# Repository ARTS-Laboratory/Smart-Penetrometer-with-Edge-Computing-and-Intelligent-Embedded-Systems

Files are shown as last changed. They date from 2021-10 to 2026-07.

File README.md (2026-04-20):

# Smart Penetrometer with Edge Computing and Intelligent Embedded Systems (SPECIES) 
### Design and develop UAV-deployable smart sensor nodes in a network with edge computing and solar-charging capabilities for soil classification and fault detection.

<p align="center">
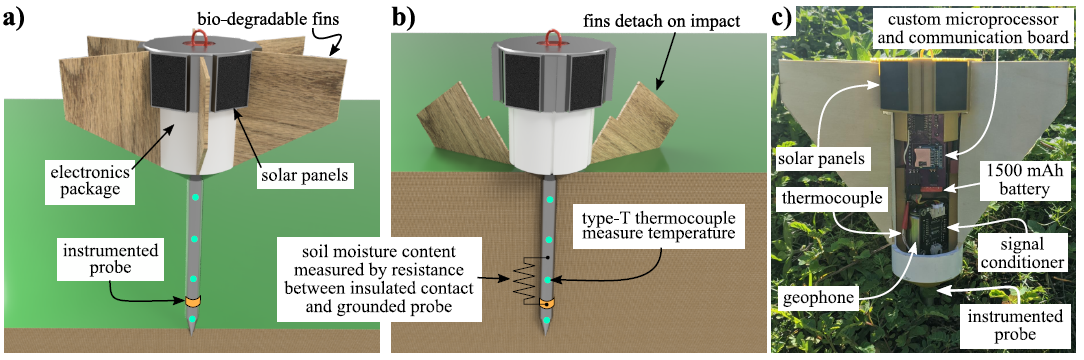
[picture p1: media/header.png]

</p>

## Licensing and Citation

[][cc-by-sa]

This work is licensed under a
[Creative Commons Attribution-ShareAlike 4.0 International License][cc-by-sa].

[cc-by-sa]: http://creativecommons.org/licenses/by-sa/4.0/
[cc-by-sa-image]: https://licensebuttons.net/l/by-sa/4.0/88x31.png
[cc-by-sa-shield]: https://img.shields.io/badge/License-CC%20BY--SA%204.0-lightgrey.svg

Cite as:

@Misc{ARTSLabSmartPenetrometerEdge,  
  author       = {ARTS-Lab},  
  howpublished = {GitHub},  
  title        = {Smart Penetrometer with Edge Computing and Intelligent Embedded Systems},  
  groups       = {ARTS-Lab},  
  url          = {https://github.com/ARTS-Laboratory/Smart-Penetrometers-with-Edge-Computing-and-Intelligent-Embedded-Systems},  
  note = {Accessed: Month dd, yyyy},   
}

<p align="center">
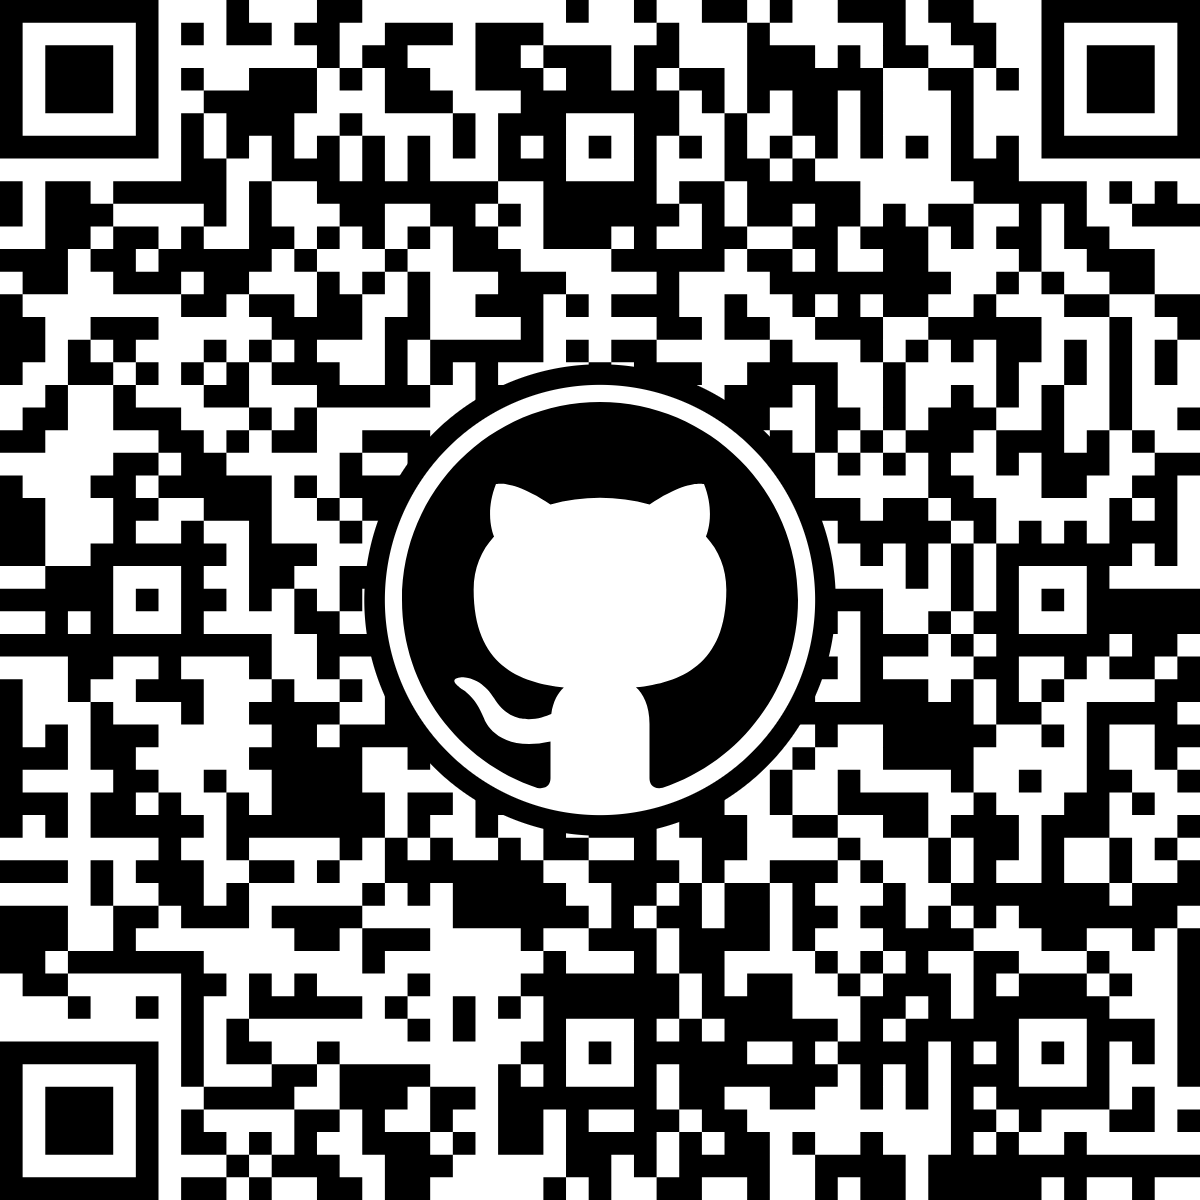
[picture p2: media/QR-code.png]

</p>
<p align="center">
QR code for repo.

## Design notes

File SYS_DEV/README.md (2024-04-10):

# Smart Penetrometer with Edge Computing and Intelligent Embedded Systems (SPECIES) - Systems Development
The SPECIES sensor package can be constructed in several versions, each named after a river with significant levee systems.

## Columbia
* The fully featured smart penetrometer with soil conductivity and temperature sensing in an intergraded spike, geophones for sensing ground movement, and  environmental condition monitoring. 

<p align="center">
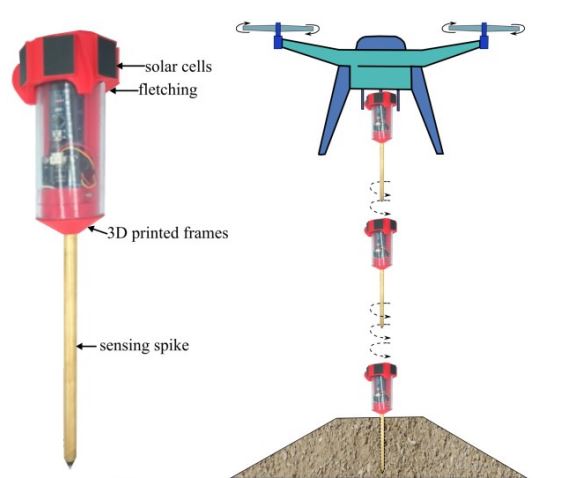
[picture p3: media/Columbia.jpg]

</p>

## Mississippi
* A wireless version of the Columbia system with only the soil moisture sensing spike.

<p align="center">
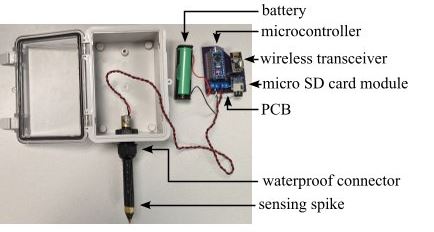
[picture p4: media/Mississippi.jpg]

</p>

## Missouri
* A geophone sensor with GPS that saves data directly to an SD card. 

<p align="center">
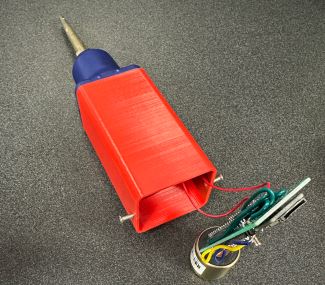
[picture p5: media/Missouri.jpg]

</p>

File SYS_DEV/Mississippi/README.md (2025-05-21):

# Mississippi

## v0.1
Files related to "spike-only" sensor package version.

### Arduino
`/Arduino/rf24_network.ino` is the code for a sensor spike node. The node's address is declared, data is collected and transmitted to the base station.

A unique address must be assigned to each node in the `this_node` variable in file `Arduino/rf24_network.ino`

`0o00` will be the address of the base station. Each node can be labeled `0o01, 0o02, etc...`

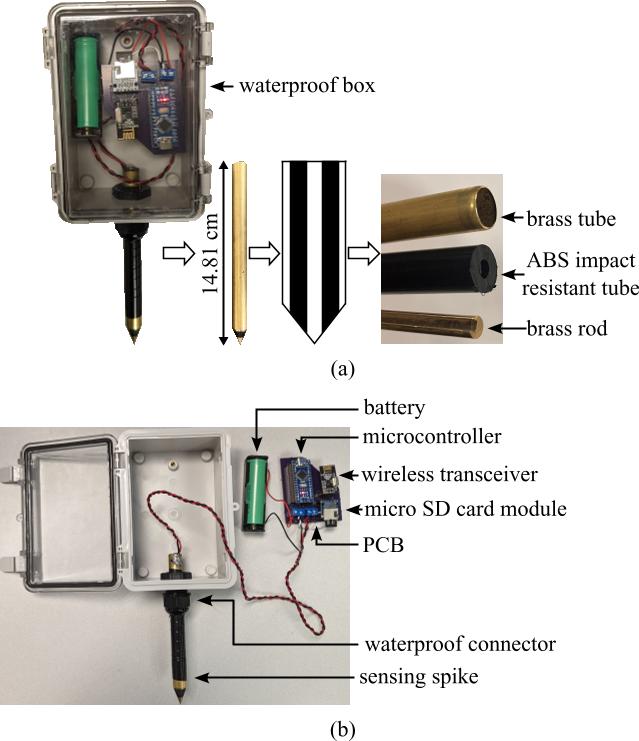
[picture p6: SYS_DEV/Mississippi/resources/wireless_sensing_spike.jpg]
Arduino Sensor Spike diagram


### RaspberryPi
`/RaspberryPi/rf24_network.py` is the code for the base station. The base station's address is established and data is recieved from the children nodes. 

All known nodes must be declared in the `OTHER_NODES` list.
Ex: for 5 nodes connected to base station `OTHER_NODES = [0o1, 0o2, 0o3, 0o4, 0o5]`

*Max of 5 nodes able to connect to nRF24L01+ chip at once.

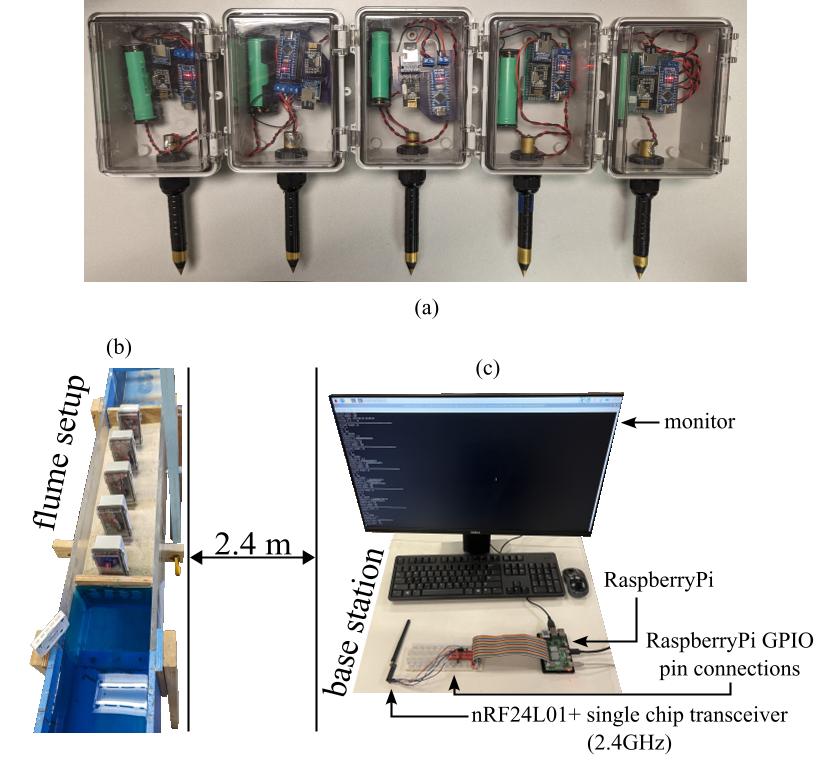
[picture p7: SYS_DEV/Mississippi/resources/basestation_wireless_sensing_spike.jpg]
Base Station diagram


### Spike PCB
PCB for a sensor spike node.

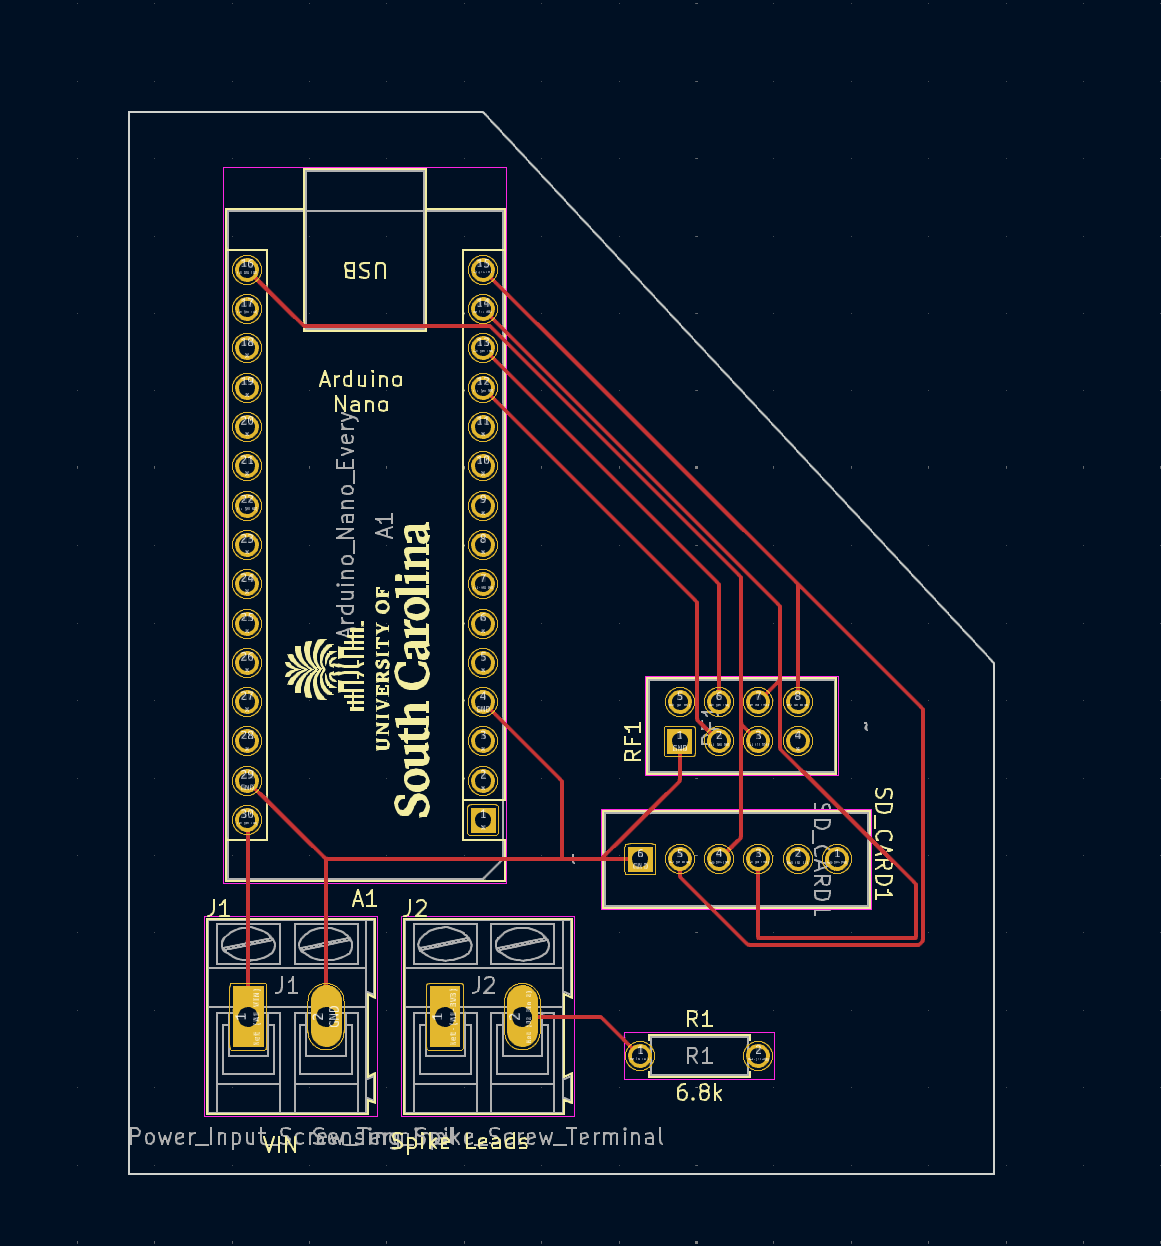
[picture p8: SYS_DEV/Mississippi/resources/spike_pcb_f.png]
Spike PCB Front
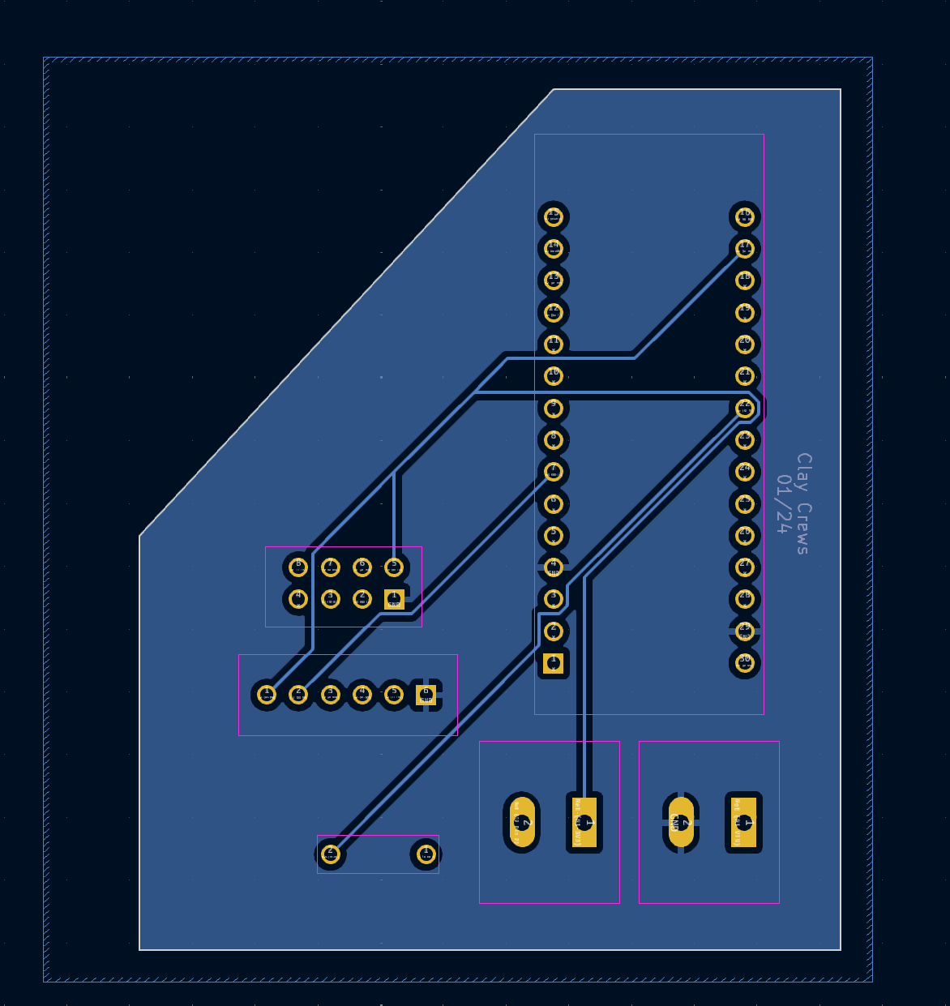
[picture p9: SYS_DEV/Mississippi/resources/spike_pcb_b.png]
Spike PCB Back


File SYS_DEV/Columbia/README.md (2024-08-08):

# Columbia 

<!-- This is a single-line comment and won't appear in the rendered README 
```angular2html      
📄 README.md
📄 image.PNG
```-->

<p align="center">
<img src="https://user-images.githubusercontent.com/87868879/166610946-1d7f9edc-2c42-431b-8995-1c52ac2c5b0f.png" alt="image" width="500"/>
</p>
<p align="center">
<img src="https://github.com/ARTS-Laboratory/Smart-Penetrometer-with-Edge-Computing-and-Intelligent-Embedded-Systems/assets/87868879/c0358ba6-607f-4f89-94c0-40613c4a618a" alt="image" width="500"/>
</p>

## [V0](V0)
### Sensor node beta version 
1. Development of sensor node prototype.
1. A sensor node that collects data and saves it to local memory.

## [V1](V1)
### Sensor node official verison (future goal)
1. Can communicate with a base station
2. Lasts for over a week.

## [V2](V2)
### Sensor node in a network (future goal)
1. Can communicate and pass data between nodes.
2. Communication protocol for passing information developed.
3. Build a way-station to collect data from a network of sensors and communicate to the cloud.

## [V3](V3)
### Autnonomous sensor node in network with edge computing (future goal)
1. Has edge-computing capabilities.
2. Can do Soil classification, fault detection, etc.

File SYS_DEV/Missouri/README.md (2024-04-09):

# Mississippi

An Open Source wireless geophone design built in parallel with SPECIES

<p align="center">

</p>
<p align="center">
The wireless geophone system being developed.
</p>

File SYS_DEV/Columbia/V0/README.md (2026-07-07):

# V0
## [V0.1](V0.1)
1. Arduino Nano for microcontroller.
2. Real-time clock and SD card module for data logging.
3. Environmental sensor, slide switch, and battery input.
4. 2-pin and 3-pin connectors for geophone and TDS sensors, respectively.
5. Op-amp and ADC for geophone signal processing.
## [V0.2](V0.2)
1. Added 4-pin connector for accelerometer.
2. Removed op-amp.
## [V0.3](V0.3)
1. Added solar power input.
2. Added 3v3 voltage regulator, Zener diode, and 2 Schottsky diodes for power management.
## [V0.4](V0.4)
1. A working version with geophone and conductivity probe.
2. Saves data to SD card.
3. No solar.
4. All needed design files in this folder.
## [V0.5](V0.5)
1. Adds wireless communication.
2. Adds solar charger.
3. Adds RTD sensor.
## [V0.6](V0.6)
1. Corrected 3V3 voltage regulator.
2. Added Op-Amp and clipper circuit for geophone.
3. Added jumpers for switching between USB and battery power.
4. Doubled amount of solar cells to six.
5. Updated housing to include geophone and and ease wiring and assembly process.
## [V0.7](V0.7)
1. More robust spike head
2. Upgrade considerations for assembly
## [Return to Main ReadMe](https://github.com/ARTS-Laboratory/Smart-Penetrometers-with-Edge-Computing-and-Intelligent-Embedded-Systems/blob/main/README.md)

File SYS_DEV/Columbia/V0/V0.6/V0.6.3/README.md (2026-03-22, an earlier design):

# V 0.6.3
## Sensor node
1. Extended battery life through hardware and software changes.
2. Removed solar charging.
3. Removed jumpers.
4. Added SN74LVC8T245DGVR logic leveler.
5. Added powerdown logic to code when idle.
6. Reduced data transimssions to once an hour.
7. Replaced solar cap with minimal cap design.

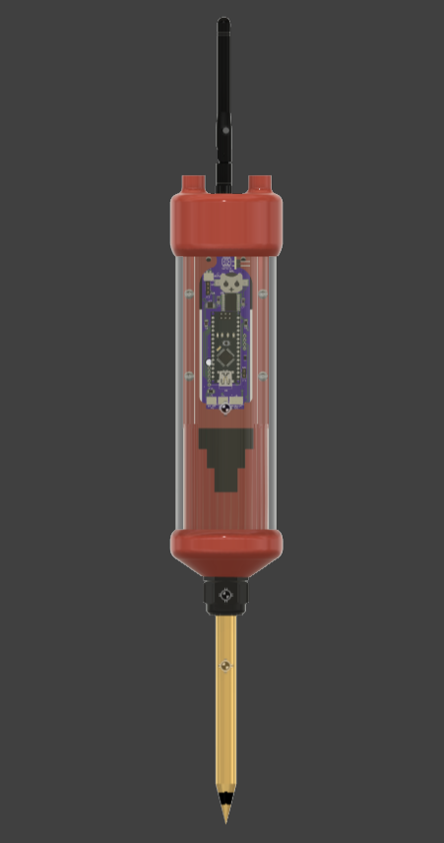
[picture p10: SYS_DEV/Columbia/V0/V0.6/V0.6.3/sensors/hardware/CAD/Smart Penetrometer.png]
Sensor


## [Return to V0.6](https://github.com/ARTS-Laboratory/Smart-Penetrometer-with-Edge-Computing-and-Intelligent-Embedded-Systems/blob/main/V0/V0.6)

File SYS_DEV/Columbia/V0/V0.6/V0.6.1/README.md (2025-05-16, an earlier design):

# V 0.6.1
Sensor node
1. A sensor node that collects data, saves it to local memory, and sends it wirelessly to gateway station.
1. Utilizes solar recharging.
1. 4-layer PCB
2. Incorporates geophone
3. Six solar cells
4. Improve waterproof seals
5. Replaced ADS1118 with ADS1115 due to spi mode incompatibility.
6. RTD, EC, and Geophone sensors all read through ADS1118.
7. Collected data stored on raspberry pi and in a dropbox client.
8. Service script initiates data collection on boot.
9. A new folder is generated each day, and each node's data is stored in a seperate file.

<p align="center">

</p>

## [Return to V0.6](https://github.com/ARTS-Laboratory/Smart-Penetrometer-with-Edge-Computing-and-Intelligent-Embedded-Systems/blob/main/V0/V0.6)

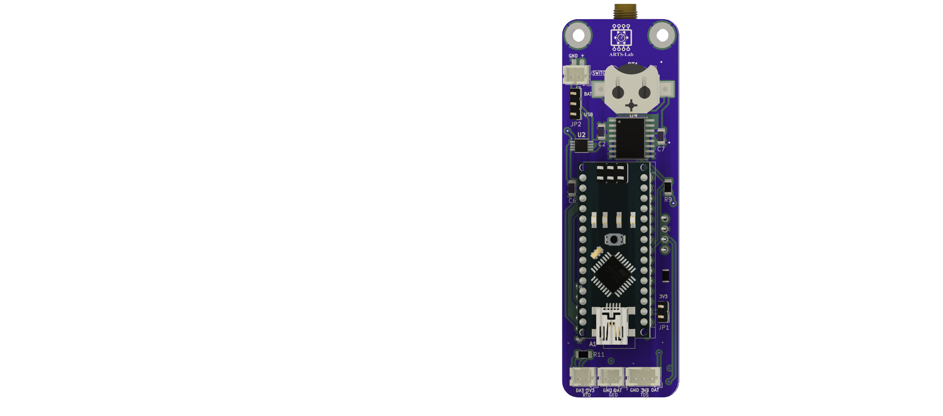
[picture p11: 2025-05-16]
SYS_DEV/Columbia/V0/V0.7/v0.7.0/sensors/hardware/PCB/smart penetrometer/smart penetrometer.kicad_pro/PCB_Front.png

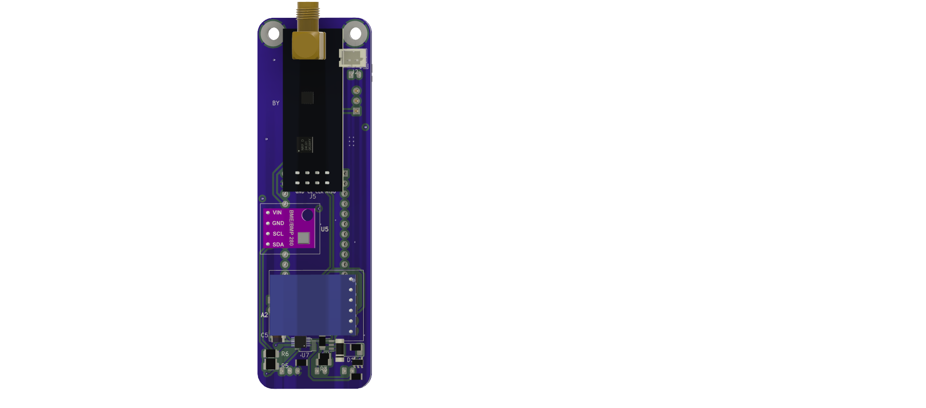
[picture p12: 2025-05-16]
SYS_DEV/Columbia/V0/V0.7/v0.7.0/sensors/hardware/PCB/smart penetrometer/smart penetrometer.kicad_pro/PCB_Back.png

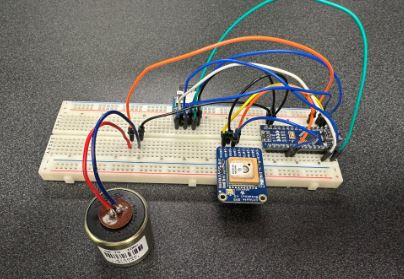
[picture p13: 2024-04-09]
SYS_DEV/Missouri/media/system.JPG

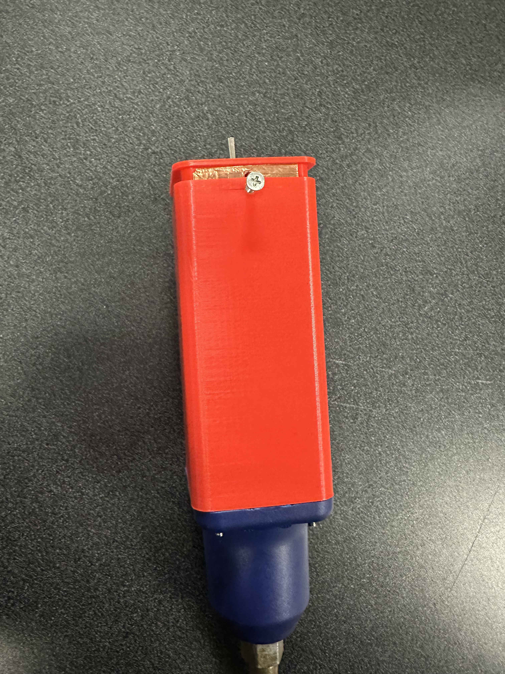
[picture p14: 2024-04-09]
SYS_DEV/Missouri/V0.2/V0.2 Housing.jpg

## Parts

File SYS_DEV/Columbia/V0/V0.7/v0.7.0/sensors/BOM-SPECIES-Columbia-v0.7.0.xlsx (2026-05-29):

Designator | Component | Amount in Inventory | Amount per Package | Individual Cost | Total Cost | Notes | Vendor 1 | Vendor 2 | Vendor 3 | Vendor 4 | Vendor 5 | Vendor 6
outer brass tube - spike probe | 260 Brass Round Tube: 17/32 in Outside Dia, 0.503 in Inside Dia, 0.014 in Wall Thick, 260, Mill |  | 1 | $6.57 | $6.57 | Slides onto the plastic tube easily. | https://www.grainger.com/product/260-Brass-Round-Tube-17-32-48KU83?opr=ODOH&analytics=FM:Order%20History
inner brass rod - spike probe | 360 Brass Rod: 1/4 in Outside Dia, 36 in Overall Lg, H02, Mill, 45,000 psi Yield Strength, Inch |  | 0.125 | $16.45 | $2.06 | longest piece with free shipping on USC contract | https://www.grainger.com/product/360-Brass-Rod-1-4-in-Outside-803H35?opr=ILOF
abs tube - spike probe | ABS Tube Stock: 3 ft Lg, 1/4 in Inside Dia, 1/2 in Outside Dia, 0.13 in Wall Thick, Opaque, Black |  | 0.167 | $13.59 | $2.27 | longest piece with free shipping on USC contract | https://www.grainger.com/product/ABS-Tube-Stock-3-ft-Lg-60CY12?opr=ODOH&analytics=FM:Order%20History
heat shrink - spike probe | SHRINK-KON Heat Shrink Tubing: 0.75 in I.D. Before Shrinking, 0.38 in I.D. After Shrinking, 10 PK |  | 0.1 | $7.76 | $0.78 |  | https://www.grainger.com/product/SHRINK-KON-Heat-Shrink-Tubing-0-75-in-3KH60?opr=ILOF
Double Split Shaft Locking Collar | 1/2" Bore Double Split Shaft Locking Collar Black Oxide Finish |  | 1 | $4.48 | $4.48 |  | https://www.mscdirect.com/product/details/65021594 | https://www.grainger.com/product/DAYTON-Shaft-Collar-2-Piece-1L698
Gorilla Glue | Gorilla Glue Original |  | 0.01 | $9.98 | $0.10 | Used between spike probe layers | https://www.grainger.com/product/GORILLA-Glue-Gen-Purpose-1TMA1 | Gorilla 8 oz. Original Glue 50008A - The Home Depot (https://www.homedepot.com/p/Gorilla-8-oz-Original-Glue-50008A/100204163)
 |  |  |  | Total | $16.25

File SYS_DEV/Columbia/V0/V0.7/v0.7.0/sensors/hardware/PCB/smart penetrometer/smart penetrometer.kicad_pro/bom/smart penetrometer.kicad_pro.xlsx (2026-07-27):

Item # | Reference | Qty | Manufacturer | Product # | Description / Value | Package | Footprint | Unit Price | Cost | Links
1 | A1 | 1 | Arduino | A000005 | ARDUINO NANO ATMEGA328 EVAL BRD |  |  | $24.90 | $24.90 | link
2 | A2 | 1 |  |  | SD_Card_Module |  | kitest:SD Module |  | $- | link
3 | BT1 | 1 | MPD | BK-870 | BATTERY RETAINER COIN 10MM SMD |  |  | $0.58 | $0.58 | link
4 |  | 1 | Renata Batteries | CR1025 | BATTERY LITHIUM 3V COIN 10MM |  |  | $1.40 | $1.40 | link
5 | C2,C6 | 2 | KEMET | C1206C104J5RACTU | C_1uF | 1206 (3216 Metric) |  | $0.24 | $0.48 | link
6 | C5,C7 | 2 | KEMET | C1206C104J5RACTU | C_0.1uF |  | Capacitor_SMD:C_1206_3216Metric |  | $- | link
7 | D1 | 1 |  |  | SMZ1_770mV |  | Diode_SMD:D_MELF |  | $- | link
8 | J1 | 1 |  |  | RTD |  | custom:JST_PH_B2B-PH-K_1x02_P2.00mm_Vertical |  | $- | link
9 | J2,J3 | 2 |  |  | Conn_01x02 |  | custom:JST_PH_B2B-PH-K_1x02_P2.00mm_Vertical |  | $- | link
10 | J4 | 1 |  |  | GEO |  | custom:JST_PH_B2B-PH-K_1x02_P2.00mm_Vertical |  | $- | link
11 | J5 | 1 |  |  | Conn_02x04 |  | Connector_PinSocket_2.54mm:PinSocket_2x04_P2.54mm_Vertical |  | $- | link
12 | J6 | 1 |  |  | EC |  | custom:JST_PH_B3B-PH-K_1x03_P2.00mm_Vertical |  | $- | link
13 | JP1 | 1 |  |  | Jumper_2 |  | Connector_PinHeader_2.54mm:PinHeader_1x02_P2.54mm_Vertical |  | $- | link
14 | JP2 | 1 |  |  | Jumper_3 |  | Connector_PinHeader_2.54mm:PinHeader_1x03_P2.54mm_Vertical |  | $- | link
15 | R1 | 1 |  |  | R_32K |  | Resistor_SMD:R_1206_3216Metric |  | $- | link
16 | R2 | 1 |  |  | R_7.5K |  | Resistor_SMD:R_1206_3216Metric |  | $- | link
17 | R3 | 1 |  |  | R_100 |  | Resistor_SMD:R_1206_3216Metric |  | $- | link
18 | R5,R6,R11 | 3 |  |  | R_10K |  | Resistor_SMD:R_1206_3216Metric |  | $- | link
19 | R9,R10 | 2 |  |  | R_1kOhm |  | Resistor_SMD:R_1206_3216Metric |  | $- | link
20 | U1 | 1 |  |  | LM321 |  | Package_TO_SOT_SMD:SOT-23-5 |  | $0.10 | link (https://www.digikey.com/en/products/detail/shenzhen-slkormicro-semicon-co-ltd/LM321/21852988)
21 | U2 | 1 |  |  | ADP124ARHZ-3.3-R7 |  | footprint:RH_8_1_ADI |  | $2.52 | link1 (https://www.digikey.com/en/products/detail/analog-devices-inc/ADP124ARHZ-3.3-R7/2237789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) | link2 (https://www.ebay.com/itm/365432072865?var=635230515876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)
22 | U4 | 1 |  |  | DS3231M |  | Package_SO:SOIC-16W_7.5x10.3mm_P1.27mm |  | $- | link
23 | U5 | 1 |  |  | BME260 |  | kitest:BME260 |  | $- | link
24 | U7 | 1 |  |  | ADS1115IDGS |  | Package_SO:TSSOP-10_3x3mm_P0.5mm |  | $5.28 | link1 (https://www.digikey.com/en/products/detail/texas-instruments/ADS1115IDGSR/2231567) | link2 (https://www.ebay.com/itm/293687781658?_skw=ADS1115IDGSR&itmmeta=01KYGADFZC6XKXNJYDE79P6MAW)
 |  |  |  |  |  |  |  | Total Cost | $35.26

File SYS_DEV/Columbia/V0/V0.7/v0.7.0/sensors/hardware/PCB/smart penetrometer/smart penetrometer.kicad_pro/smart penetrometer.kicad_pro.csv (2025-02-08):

Source: | C:\USC\Smart-Penetrometer-with-Edge-Computing-and-Intelligent-Embedded-Systems\System_development\Columbia\V0\V0.6\V0.6.1\sensor_node\hardware_design\PCB\smart penetrometer\smart penetrometer.kicad_sch
Date: | 2/8/2025 1:21:20 AM
Tool: | Eeschema 7.0.2
Generator: | C:\Program Files\KiCad\7.0\bin\scripting\plugins/bom_csv_grouped_by_value.py
Component Count: | 29
Collated Components:
Item | Qty | Reference(s) | Value | LibPart | Footprint | Datasheet | DNP | 1 | 2 | 3 | 4
1 | 1 | A1 | Arduino Nano | smart-penetrometer-update-rescue:Arduino_Nano_v3.x-MCU_Module-kitest-rescue-smart-penetrometer-rescue-smart-penetrometer-update-rescue | Module:Arduino_Nano | http://www.mouser.com/pdfdocs/Gravitech_Arduino_Nano3_0.pdf
2 | 1 | A2 | SD_Card_Module | smart-penetrometer-update-rescue:SD_Card_Module-Charleslabs_Parts-kitest-rescue-smart-penetrometer-rescue-smart-penetrometer-update-rescue | kitest:SD Module
3 | 1 | BT1 | Battery_Cell | Device:Battery_Cell | kitest:battery_holder_10mm | ~
4 | 2 | C2, C6 | C_1uF | Device:C_Small | Capacitor_SMD:C_1206_3216Metric | ~
5 | 2 | C5, C7 | C_0.1uF | Device:C_Small | Capacitor_SMD:C_1206_3216Metric | ~
6 | 1 | D1 | SMZ1_770mV | Diode:SMZxxx | Diode_SMD:D_MELF | https://diotec.com/tl_files/diotec/files/pdf/datasheets/smz1.pdf
7 | 2 | H1, H2 | MountingHole_Pad | Mechanical:MountingHole_Pad | MountingHole:MountingHole_3.2mm_M3_Pad | ~
8 | 2 | J2, J3 | Conn_01x02 | Connector:Conn_01x02_Female | Connector_PinSocket_2.54mm:PinSocket_1x02_P2.54mm_Horizontal | ~
9 | 1 | J4 | Conn_01x07_Female | Connector:Conn_01x07_Female | Connector_PinSocket_2.54mm:PinSocket_1x07_P2.54mm_Horizontal | ~
10 | 1 | J5 | Conn_02x04 | Connector_Generic_MountingPin:Conn_02x04_Odd_Even_MountingPin | Connector_PinSocket_2.54mm:PinSocket_2x04_P2.54mm_Vertical | ~
11 | 1 | JP1 | Jumper_2 | Jumper:Jumper_2_Open | Connector_PinHeader_2.54mm:PinHeader_1x02_P2.54mm_Vertical | ~
12 | 1 | JP2 | Jumper_3 | Jumper:Jumper_3_Open | Connector_PinHeader_2.54mm:PinHeader_1x03_P2.54mm_Vertical | ~
13 | 1 | R1 | R_32K | Device:R_Small_US | Resistor_SMD:R_1206_3216Metric | ~
14 | 1 | R2 | R_7.5K | Device:R_Small_US | Resistor_SMD:R_1206_3216Metric | ~
15 | 1 | R3 | R_100 | Device:R_Small_US | Resistor_SMD:R_1206_3216Metric | ~
16 | 3 | R5, R6, R11 | R_10K | Device:R_Small_US | Resistor_SMD:R_1206_3216Metric | ~
17 | 2 | R9, R10 | R_1kOhm | Device:R_Small_US | Resistor_SMD:R_1206_3216Metric | ~
18 | 1 | U1 | LM321 | Amplifier_Operational:LM321 | Package_TO_SOT_SMD:SOT-23-5 | http://www.ti.com/lit/ds/symlink/lm321.pdf
19 | 1 | U2 | ADP124ARHZ-3.3-R7 | smart penetrometer update-rescue:ADP124ARHZ-3.3-R7 | footprint:RH_8_1_ADI | https://www.analog.com/media/en/technical-documentation/data-sheets/ADP124_125.pdf
20 | 1 | U4 | DS3231M | Timer_RTC:DS3231M | Package_SO:SOIC-16W_7.5x10.3mm_P1.27mm | http://datasheets.maximintegrated.com/en/ds/DS3231.pdf
21 | 1 | U5 | BME260 | 4xxx:4023 | kitest:BME260 | http://www.intersil.com/content/dam/Intersil/documents/cd40/cd4011bms-12bms-23bms.pdf |  | SDA | SCL | V | G
22 | 1 | U7 | ADS1115IDGS | Analog_ADC:ADS1115IDGS | Package_SO:TSSOP-10_3x3mm_P0.5mm | http://www.ti.com/lit/ds/symlink/ads1113.pdf

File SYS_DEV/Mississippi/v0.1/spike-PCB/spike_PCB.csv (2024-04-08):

Source: | /home/jccrews/Documents/SensorSpike/spike_PCB/spike_PCB.kicad_sch
Date: | Wed 10 Jan 2024 12:13:42 PM EST
Tool: | Eeschema 7.0.10-7.0.10~ubuntu20.04.1
Generator: | /usr/share/kicad/plugins/bom_csv_grouped_by_value_with_fp.py
Component Count: | 6
Ref | Qnty | Value | Cmp name | Footprint | Description | Vendor | DNP
A1 | 1 | Arduino_Nano_Every | Arduino_Nano_Every | Module:Arduino_Nano | Arduino Nano Every
J1 | 1 | Power_Input_Screw_Terminal | Screw_Terminal_01x02 | TerminalBlock:TerminalBlock_Altech_AK300-2_P5.00mm | Generic screw terminal, single row, 01x02, script generated (kicad-library-utils/schlib/autogen/connector/)
J2 | 1 | Sensing_Spike_Screw_Terminal | Screw_Terminal_01x02 | TerminalBlock:TerminalBlock_Altech_AK300-2_P5.00mm | Generic screw terminal, single row, 01x02, script generated (kicad-library-utils/schlib/autogen/connector/)
R1 | 1 | 6.8k | R_US | Resistor_THT:R_Axial_DIN0207_L6.3mm_D2.5mm_P7.62mm_Horizontal | Resistor, US symbol
RF1 | 1 | ~ | nRF24L01 | spike_PCB:nRF24L01
SD_CARD1 | 1 | ~ | SD_Card_Module | spike_PCB:SD_Card_Module

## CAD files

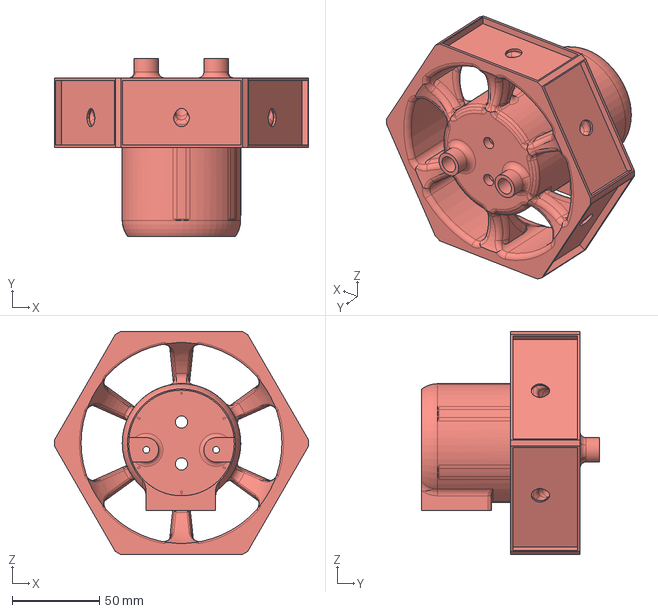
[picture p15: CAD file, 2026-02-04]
SYS_DEV/Columbia/V0/V0.7/v0.7.0/sensors/hardware/CAD/solar cap 2_.stp
145.7 x 101.8 x 128.0 mm

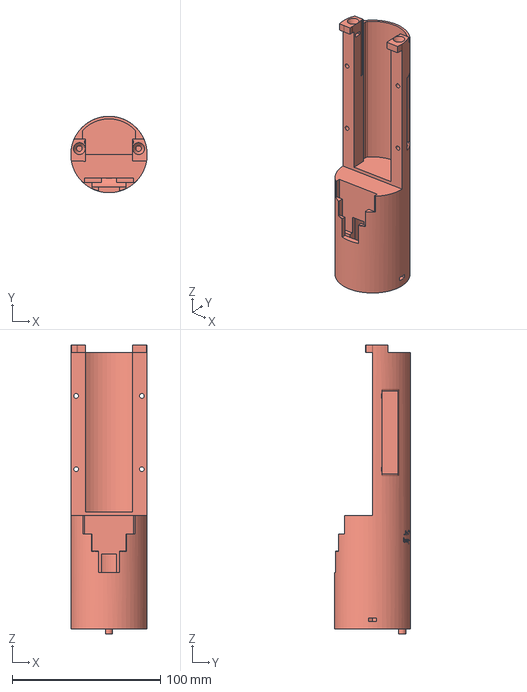
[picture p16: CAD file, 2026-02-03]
SYS_DEV/Columbia/V0/V0.7/v0.7.0/sensors/hardware/CAD/body_v0.7.0.stp
51.6 x 51.6 x 195.2 mm

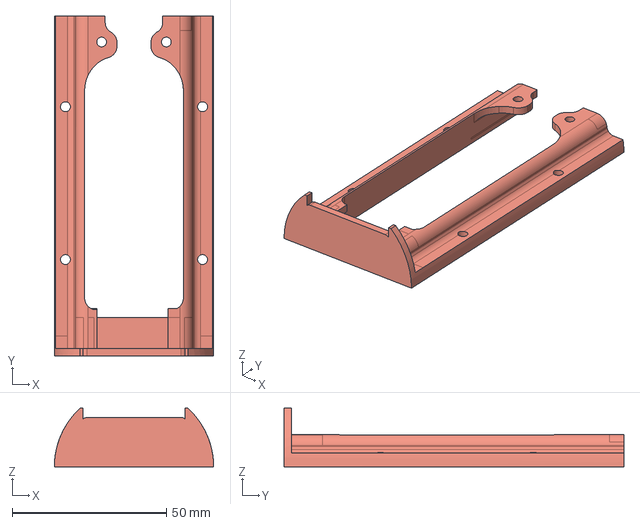
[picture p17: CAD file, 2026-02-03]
SYS_DEV/Columbia/V0/V0.7/v0.7.0/sensors/hardware/CAD/plate.stp
51.6 x 110.2 x 19.0 mm

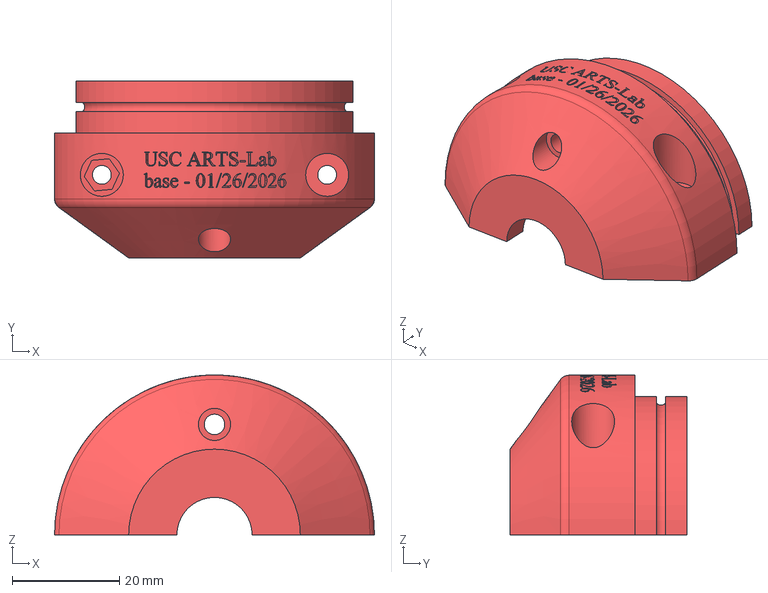
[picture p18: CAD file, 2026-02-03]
SYS_DEV/Columbia/V0/V0.7/v0.7.0/sensors/hardware/CAD/base_v0.7.0.stp
59.6 x 33.0 x 29.8 mm

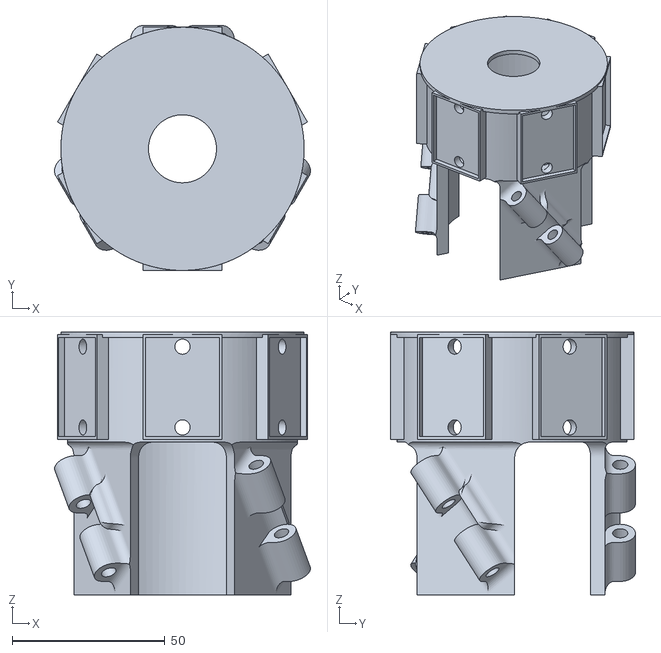
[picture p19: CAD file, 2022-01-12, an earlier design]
SYS_DEV/Columbia/V0/V0.1/V0.1.1/hardware_design/CAD/Solar panel attachment with hinge_v1.stl
83.7 x 80.1 x 86.0

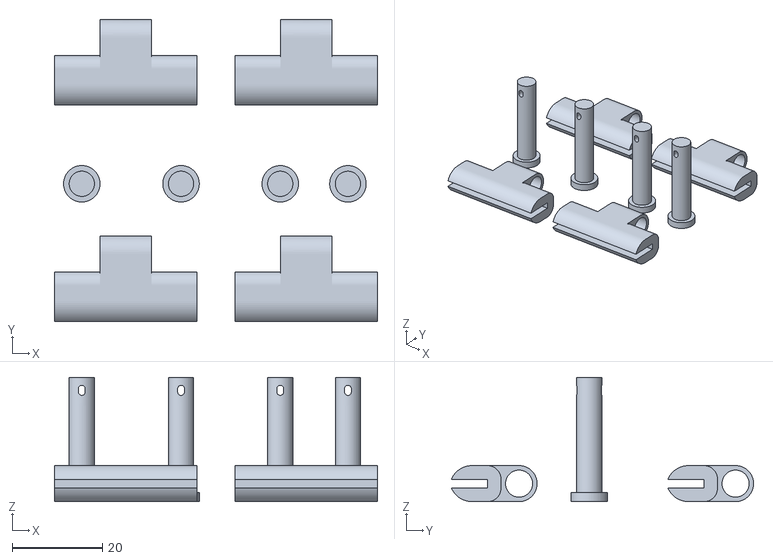
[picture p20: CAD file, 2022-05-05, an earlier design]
SYS_DEV/Columbia/V0/V0.2/V0.2.0/hardware_design/CAD/hinge and hinge pin v2.stl
71.6 x 67.0 x 27.6

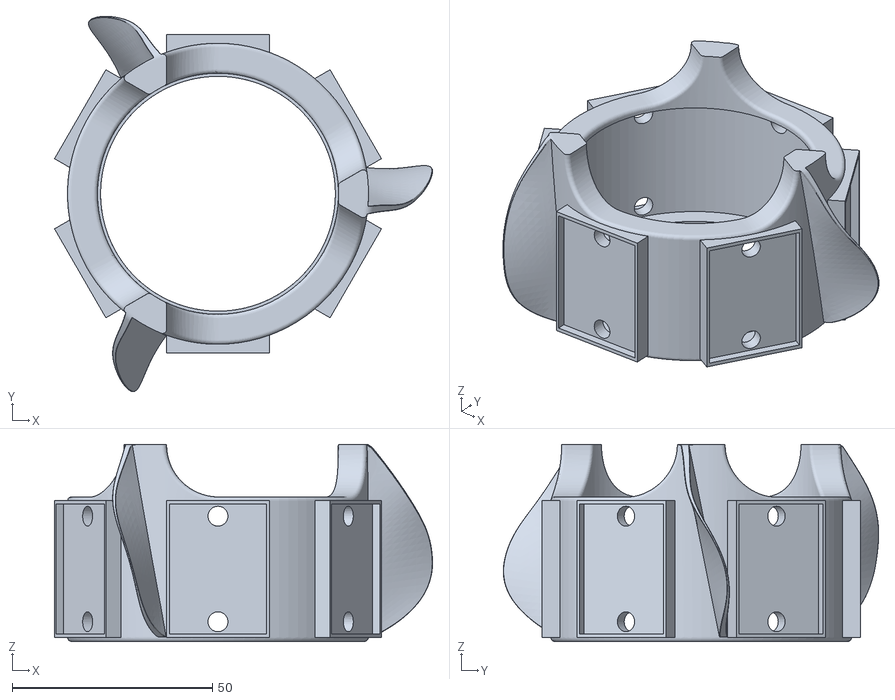
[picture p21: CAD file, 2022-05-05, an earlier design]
SYS_DEV/Columbia/V0/V0.3/V0.3.0/hardware_design/CAD/solar cells with fletching.stl
94.5 x 93.8 x 49.3

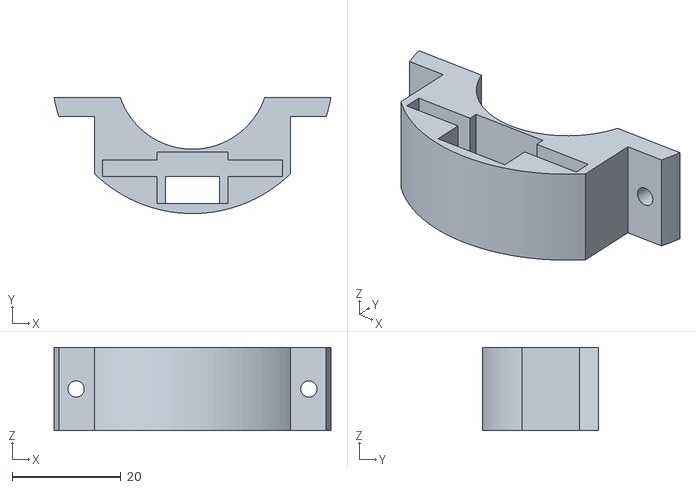
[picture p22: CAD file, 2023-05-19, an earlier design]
SYS_DEV/Columbia/V0/V0.4/V0.4.0/hardware_design/CAD/Housing v4 part 2.stl
50.9 x 21.3 x 15.2

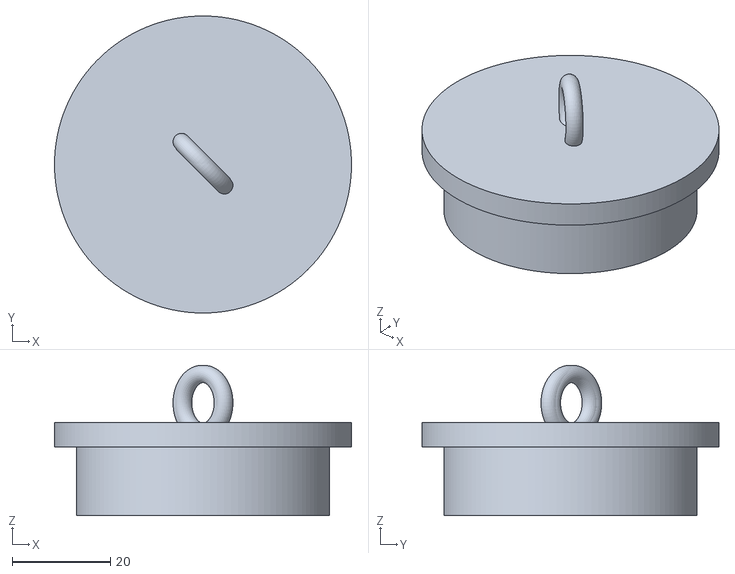
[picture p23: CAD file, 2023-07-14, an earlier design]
SYS_DEV/Columbia/V0/V0.4/V0.4.1/hardware_design/CAD/sensor_cap_v4.1.stl
60.6 x 60.6 x 30.7

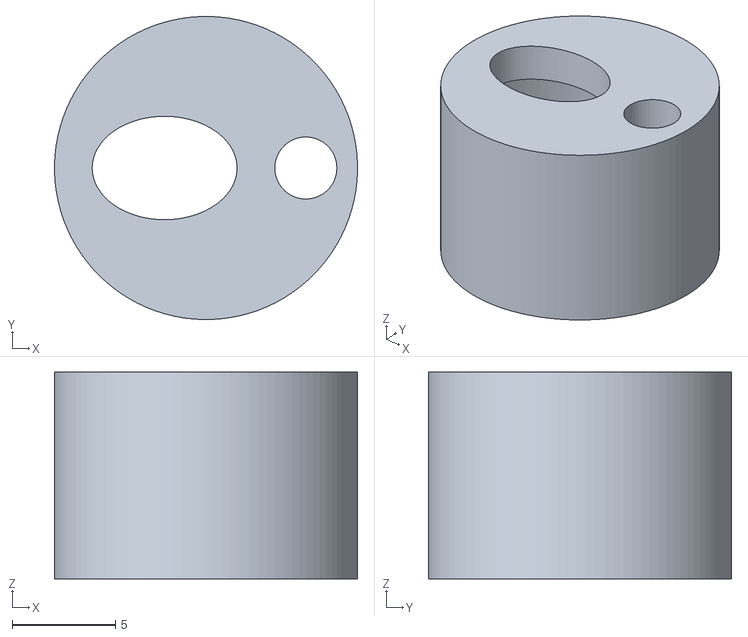
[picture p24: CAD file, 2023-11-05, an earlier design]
SYS_DEV/Columbia/V0/V0.5/V0.5.0/hardware_design/CAD/Housing3 V0.5.0b.stl
14.6 x 14.6 x 10.00

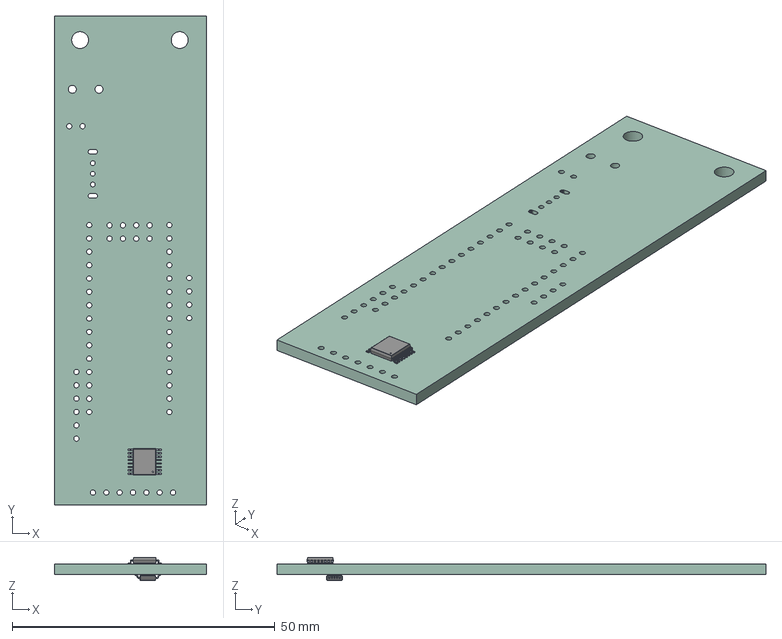
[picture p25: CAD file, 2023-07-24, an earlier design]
SYS_DEV/Columbia/V0/V0.5/V0.5.0/hardware_design/PCB/smart penetrometer/smart penetrometer.step
29.0 x 93.0 x 4.38 mm
smart penetrometer PCB

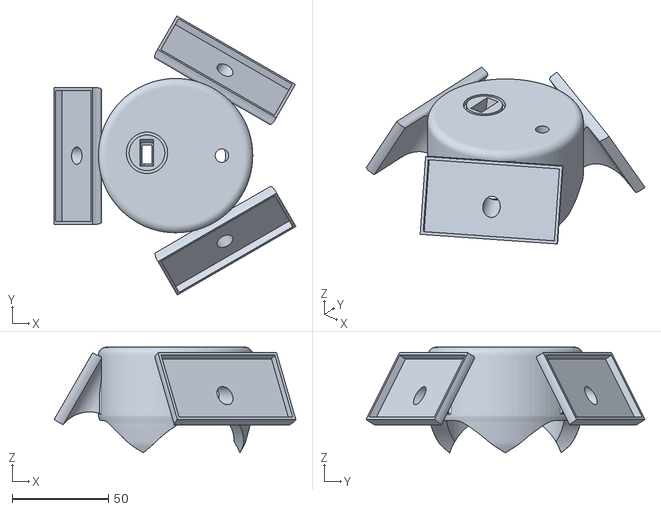
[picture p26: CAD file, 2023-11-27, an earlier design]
SYS_DEV/Columbia/V0/V0.5/V0.5.1/hardware_design/CAD/Solar Cap_.stl
125.3 x 144.6 x 54.8

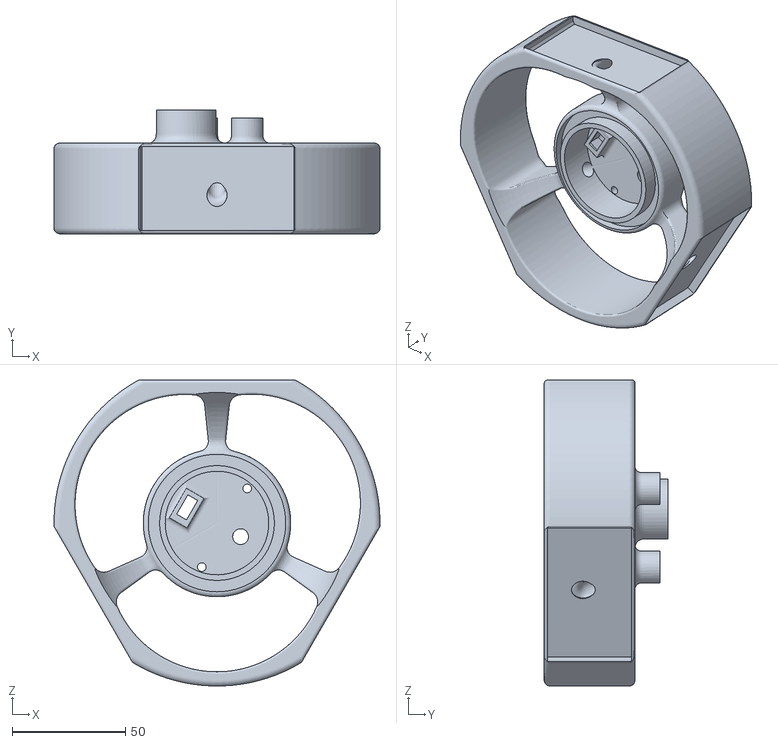
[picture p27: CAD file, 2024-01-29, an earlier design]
SYS_DEV/Columbia/V0/V0.5/V0.5.2/hardware_design/CAD/Solar Cap.stl
143.7 x 54.5 x 134.9

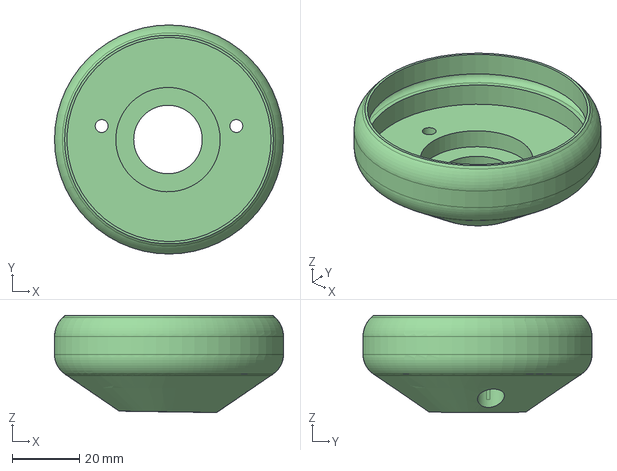
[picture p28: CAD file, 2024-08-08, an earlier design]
SYS_DEV/Columbia/V0/V0.6/V0.6.0/sensor_node/hardware_design/CAD/Housing3.step
68.0 x 68.0 x 28.8 mm

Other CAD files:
SYS_DEV/Columbia/V0/V0.6/V0.6.0/sensor_node/hardware_design/PCB/smart penetrometer/smart penetrometer.step
SYS_DEV/Columbia/V0/V0.6/V0.6.1/sensor_node/hardware_design/CAD/Housing2.step
SYS_DEV/Columbia/V0/V0.1/V0.1.0/hardware_design/CAD/housing v1.f3d
SYS_DEV/Columbia/V0/V0.1/V0.1.0/hardware_design/CAD/modified solar cell attachment v1.f3d
SYS_DEV/Columbia/V0/V0.1/V0.1.0/hardware_design/CAD/sensor_cap v1.f3z
SYS_DEV/Columbia/V0/V0.1/V0.1.1/hardware_design/CAD/Housing_v2.f3d
SYS_DEV/Columbia/V0/V0.1/V0.1.1/hardware_design/CAD/Housing_v2.stl
SYS_DEV/Columbia/V0/V0.1/V0.1.1/hardware_design/CAD/Housing_v2_part2.f3d
SYS_DEV/Columbia/V0/V0.1/V0.1.1/hardware_design/CAD/Housing_v2_part2.stl
SYS_DEV/Columbia/V0/V0.1/V0.1.1/hardware_design/CAD/Solar panel attachment with hinge_v1.f3d
SYS_DEV/Columbia/V0/V0.1/V0.1.1/hardware_design/CAD/cap_v2.f3z
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

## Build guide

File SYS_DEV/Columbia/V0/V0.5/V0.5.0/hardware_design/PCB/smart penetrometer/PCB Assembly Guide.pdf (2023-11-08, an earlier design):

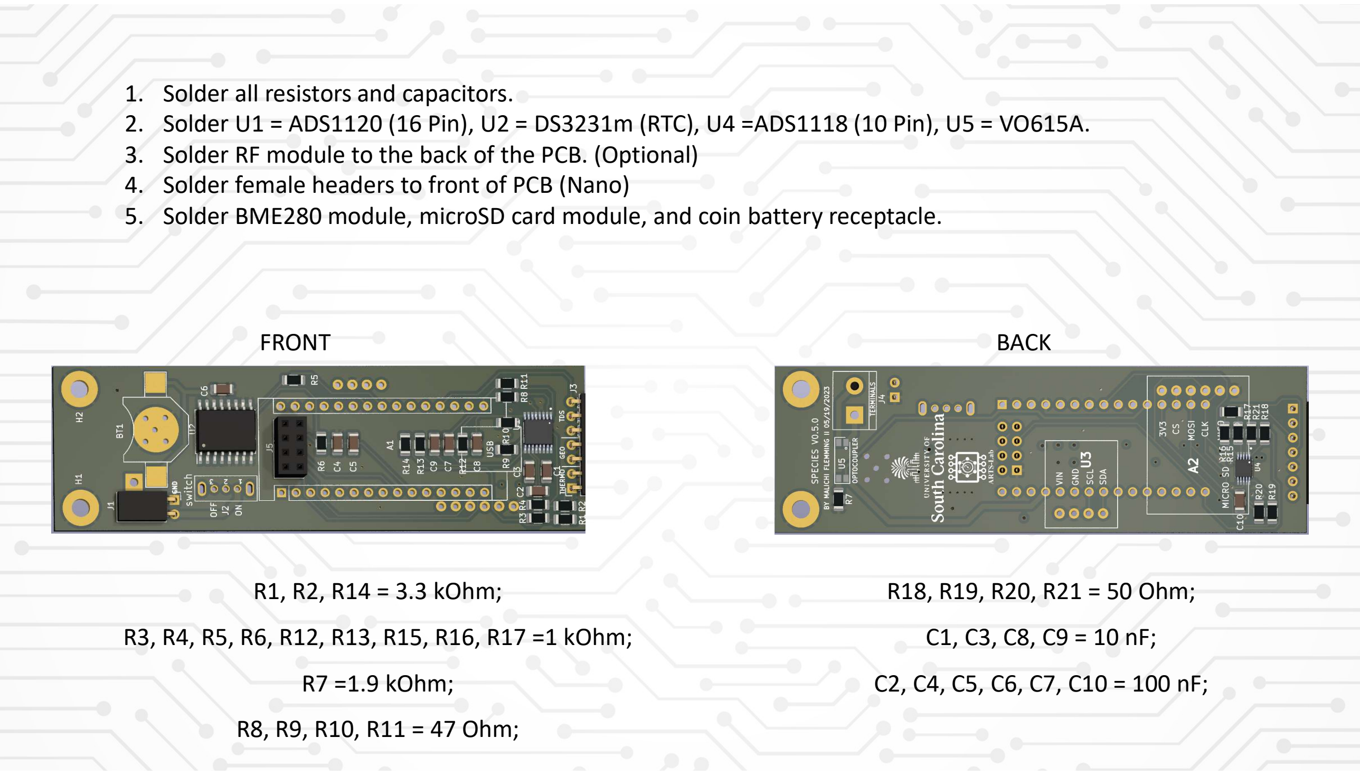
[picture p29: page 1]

R1, R2, R14 = 3.3 kOhm;
R3, R4, R5, R6, R12, R13, R15, R16, R17 =1 kOhm; R7 =1.9 kOhm;
R8, R9, R10, R11 = 47 Ohm;

R18, R19, R20, R21 = 50 Ohm; C1, C3, C8, C9 = 10 nF;
C2, C4, C5, C6, C7, C10 = 100 nF;
1. Solder all resistors and capacitors.
2. Solder U1 = ADS1120 (16 Pin), U2 = DS3231m (RTC), U4 =ADS1118 (10 Pin), U5 = VO615A.

### 3. Solder RF module to the back of the PCB. (Optional) 4. Solder female headers to front of PCB (Nano)

5. Solder BME280 module, microSD card module, and coin battery receptacle.
FRONT | BACK

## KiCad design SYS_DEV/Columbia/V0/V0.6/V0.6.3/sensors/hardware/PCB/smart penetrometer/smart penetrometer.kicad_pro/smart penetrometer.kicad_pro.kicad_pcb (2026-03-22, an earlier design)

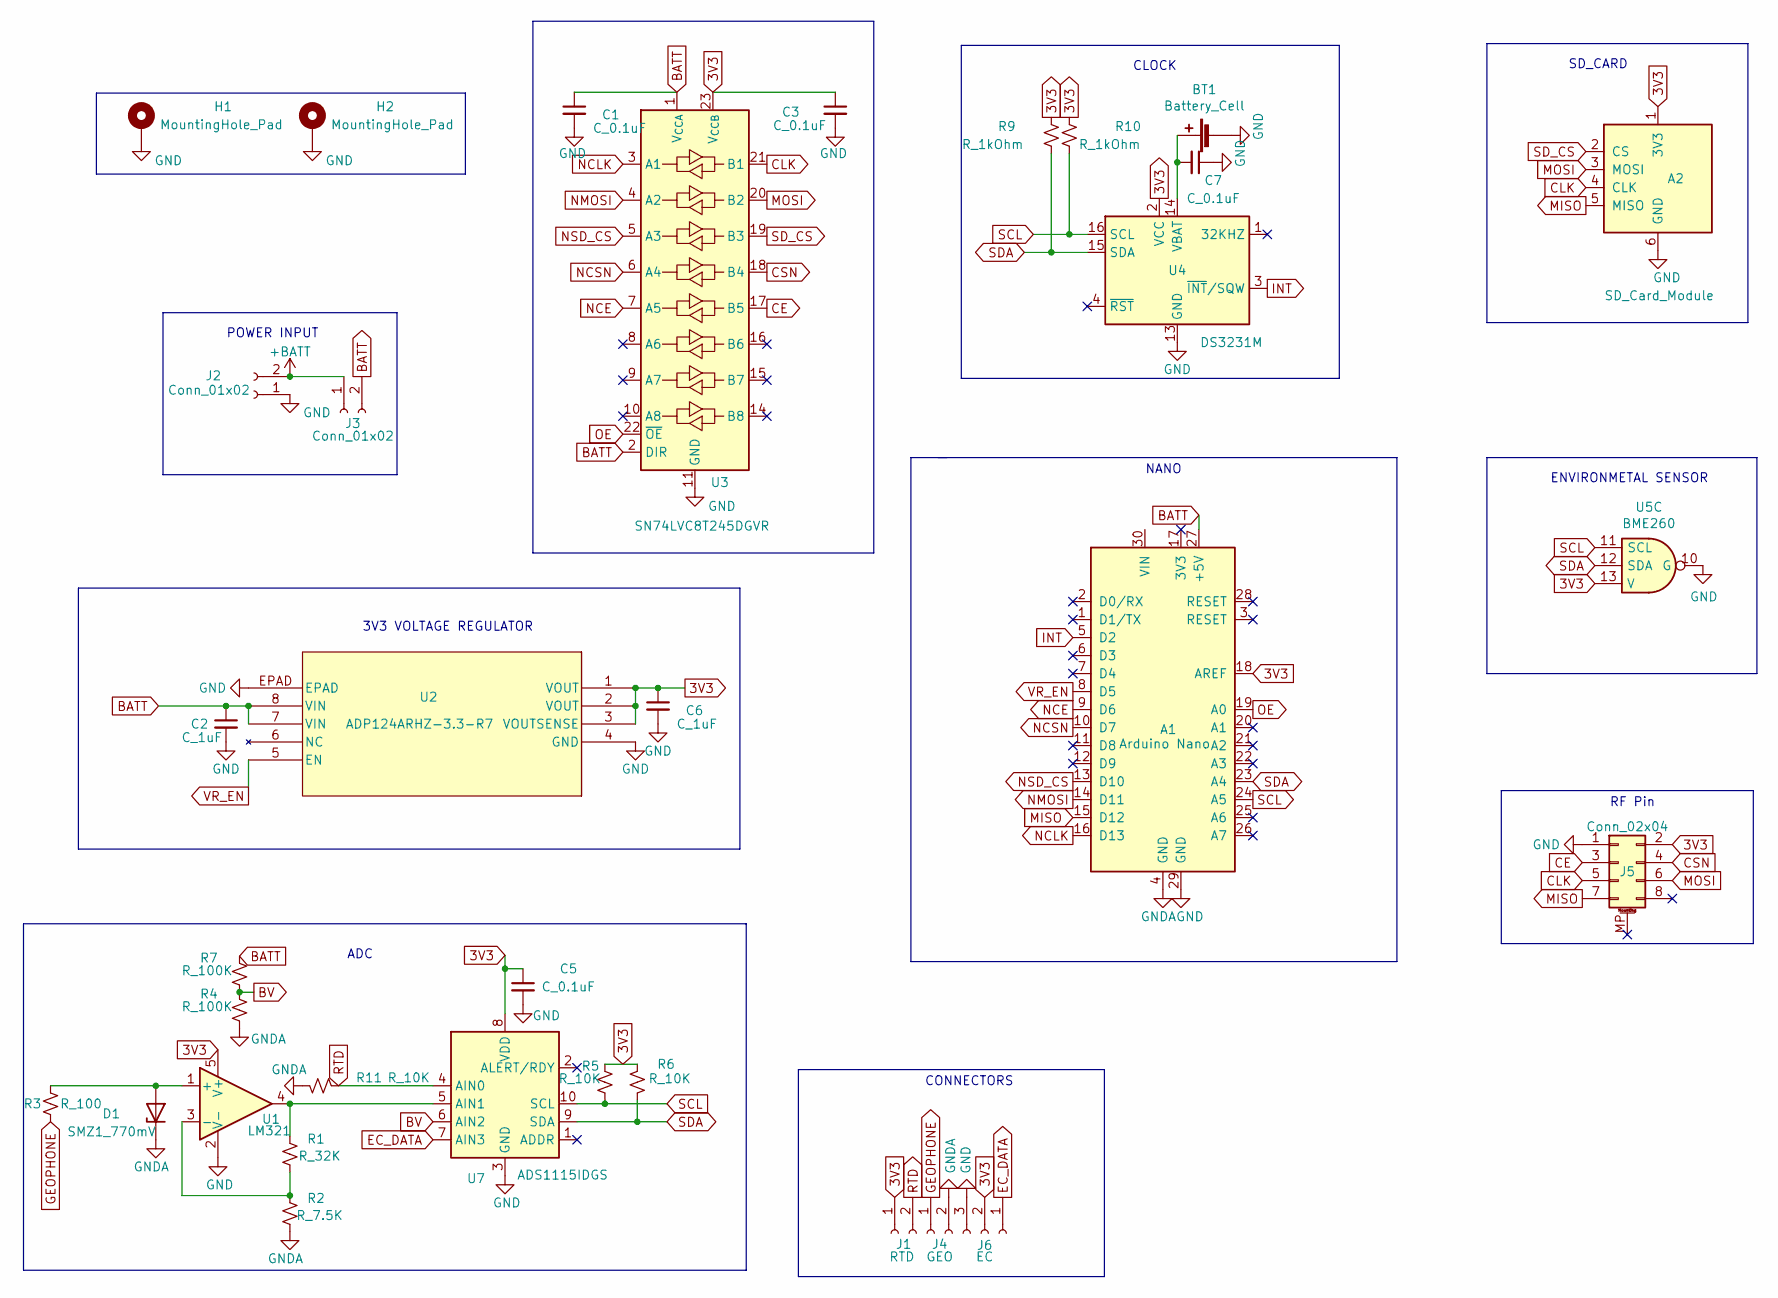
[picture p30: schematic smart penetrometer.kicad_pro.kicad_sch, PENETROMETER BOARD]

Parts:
A1: Arduino Nano; Arduino_Nano
A2: SD_Card_Module; SD Module
BT1: Battery_Cell; battery_holder_10mm
C1, C3, C5, C7: C_0.1uF; C_1206_3216Metric
C2, C6: C_1uF; C_1206_3216Metric
D1: SMZ1_770mV; D_MELF
H1, H2: MountingHole_Pad; MountingHole_3.2mm_M3_Pad
J1: RTD; JST_PH_B2B-PH-K_1x02_P2.00mm_Vertical
J2, J3: Conn_01x02; JST_PH_B2B-PH-K_1x02_P2.00mm_Vertical
J4: GEO; JST_PH_B2B-PH-K_1x02_P2.00mm_Vertical
J5: Conn_02x04; PinSocket_2x04_P2.54mm_Vertical
J6: EC; JST_PH_B3B-PH-K_1x03_P2.00mm_Vertical
R1: R_32K; R_1206_3216Metric
R2: R_7.5K; R_1206_3216Metric
R3: R_100; R_1206_3216Metric
R4, R7: R_100K; R_1206_3216Metric
R5, R6, R11: R_10K; R_1206_3216Metric
R9, R10: R_1kOhm; R_1206_3216Metric
U1: LM321; SOT-23-5
U2: ADP124ARHZ-3.3-R7; RH_8_1_ADI
U3: SN74LVC8T245DGVR; SN74LVC8T245DGVR-L
U4: DS3231M; SOIC-16W_7.5x10.3mm_P1.27mm
U5: BME260
U7: ADS1115IDGS; TSSOP-10_3x3mm_P0.5mm

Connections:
3V3: A1.18 (AREF), A2.1 (3V3), C3.1, C5.1, C6.1, J1.1, J5.2, J6.2, R5.1, R6.1, R9.1, R10.1, U1.5 (V+), U2.1 (VOUT), U2.2 (VOUT), U2.3 (VOUTSENSE), U3.23 (V_{CCB}), U3.24 (V_{CCB}), U4.2 (VCC), U5.13, U7.8 (VDD)
+BATT: J2.2, J3.1
BATT: A1.27 (+5V), C1.1, C2.1, J3.2, R7.1, U2.7 (VIN), U2.8 (VIN), U3.1 (V_{CCA}), U3.2 (DIR)
BV: R4.1, R7.2, U7.6 (AIN2)
CE: J5.3, U3.17 (B5)
CLK: A2.4 (CLK), J5.5, U3.21 (B1)
CSN: J5.4, U3.18 (B4)
EC_DATA: J6.1, U7.7 (AIN3)
GEOPHONE: J4.1, R3.1
GND: A1.29 (GND), A2.6 (GND), BT1.2 (-), C1.2, C2.2, C3.2, C5.2, C6.2, C7.1, H1.1, H2.1, J2.1, J5.1, J6.3, U1.2 (V-), U2.4 (GND), U2.EPAD, U3.11 (GND), U3.12 (GND), U3.13 (GND), U4.5 (GND), U4.6 (GND), U4.7 (GND), U4.8 (GND), U4.9 (GND), U4.10 (GND), U4.11 (GND), U4.12 (GND), U4.13 (GND), U5.10, U7.3 (GND)
GNDA: A1.4 (GND), D1.1 (K), J4.2, R2.2, R4.2, R11.2
INT: A1.5 (D2), U4.3 (~INT/SQW)
MISO: A1.15 (D12), A2.5 (MISO), J5.7
MOSI: A2.3 (MOSI), J5.6, U3.20 (B2)
NCE: A1.9 (D6), U3.7 (A5)
NCLK: A1.16 (D13), U3.3 (A1)
NCSN: A1.10 (D7), U3.6 (A4)
NMOSI: A1.14 (D11), U3.4 (A2)
NSD_CS: A1.13 (D10), U3.5 (A3)
unnamed: BT1.1 (+), C7.2, U4.14 (VBAT)
unnamed: D1.2 (A), R3.2, U1.1 (+)
unnamed: R1.2, R2.1, U1.3 (-)
unnamed: R1.1, U1.4, U7.5 (AIN1)
OE: A1.19 (A0), U3.22 (~OE)
RTD: J1.2, R11.1, U7.4 (AIN0)
SCL: A1.24 (A5), R5.2, R10.2, U4.16 (SCL), U5.11, U7.10 (SCL)
SDA: A1.23 (A4), R6.2, R9.2, U4.15 (SDA), U5.12, U7.9 (SDA)
SD_CS: A2.2 (CS), U3.19 (B3)
VR_EN: A1.8 (D5), U2.5 (EN)

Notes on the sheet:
ADC
POWER INPUT
3V3 VOLTAGE REGULATOR
NANO
CLOCK
RF Pin
CONNECTORS
SD_CARD
ENVIRONMETAL SENSOR

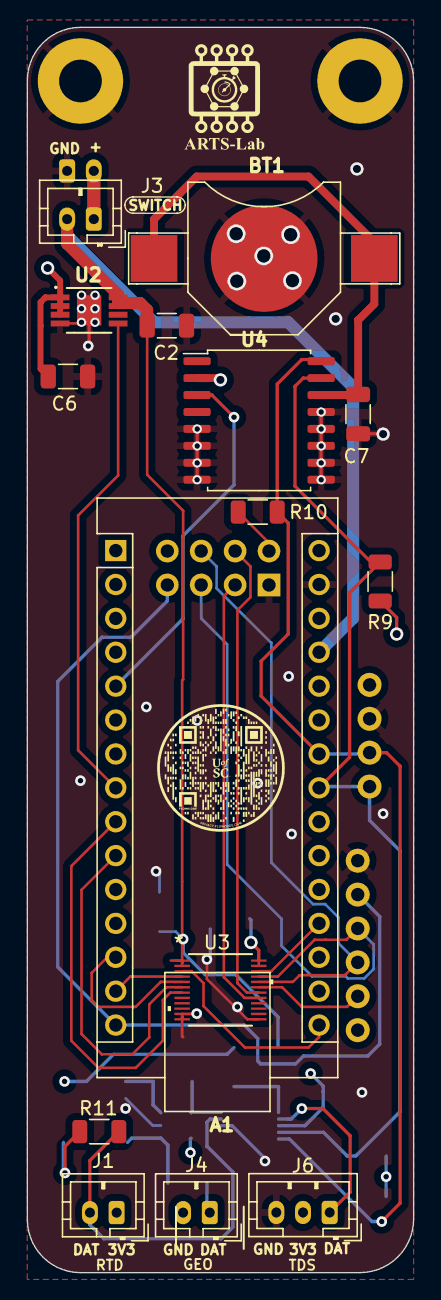
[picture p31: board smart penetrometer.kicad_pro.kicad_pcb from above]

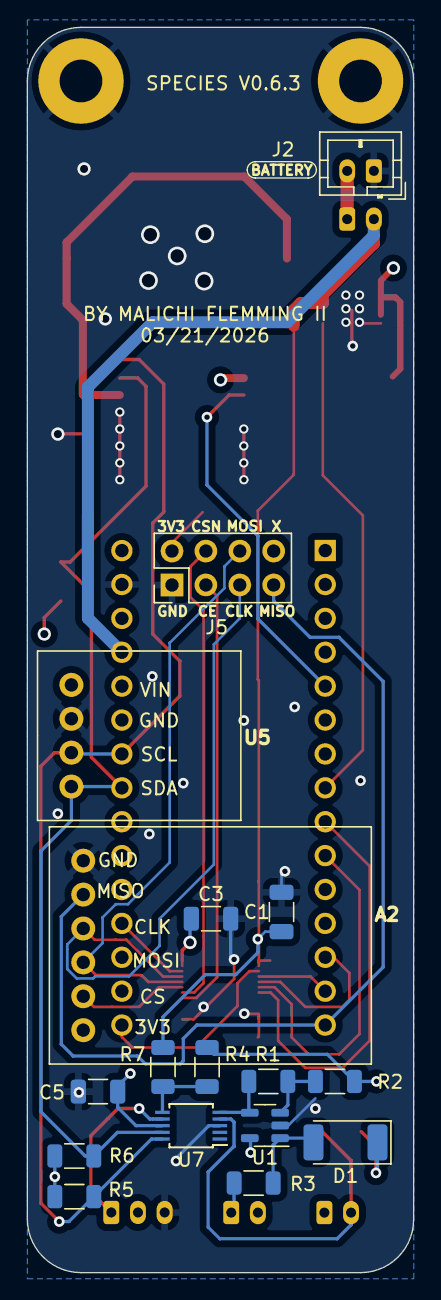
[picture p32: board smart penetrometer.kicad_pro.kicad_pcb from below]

Board: 4 copper layers, 29.0 x 93.3 mm, 34 parts (16 on the bottom side), 29 nets.

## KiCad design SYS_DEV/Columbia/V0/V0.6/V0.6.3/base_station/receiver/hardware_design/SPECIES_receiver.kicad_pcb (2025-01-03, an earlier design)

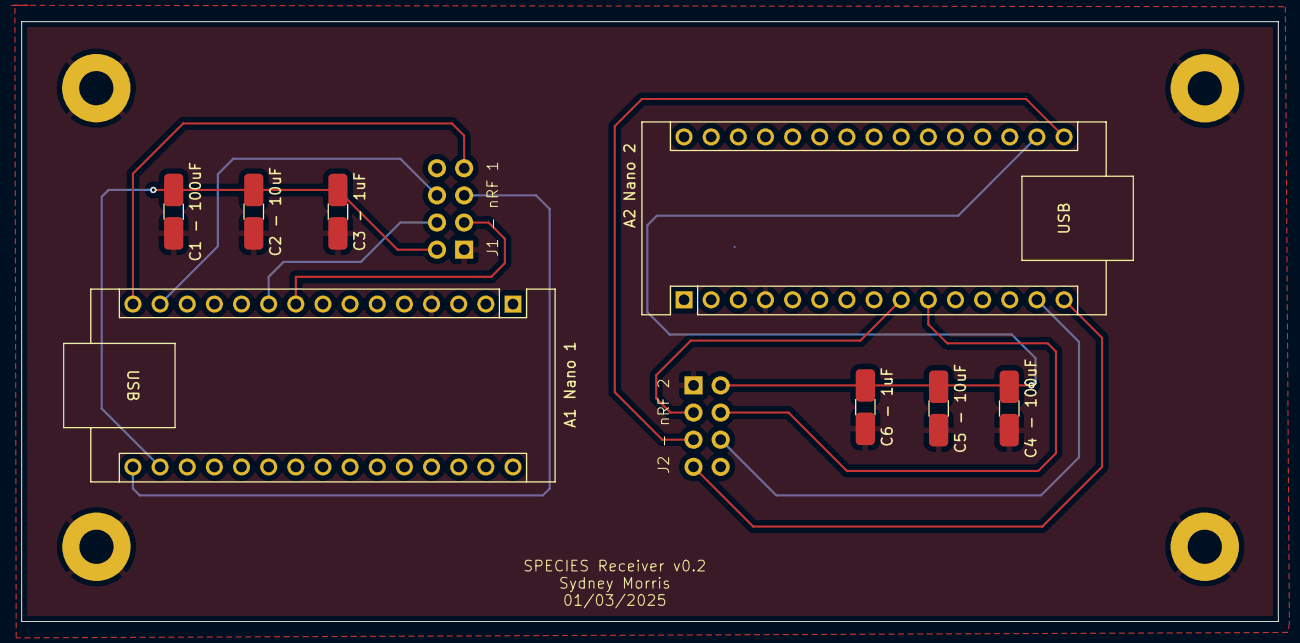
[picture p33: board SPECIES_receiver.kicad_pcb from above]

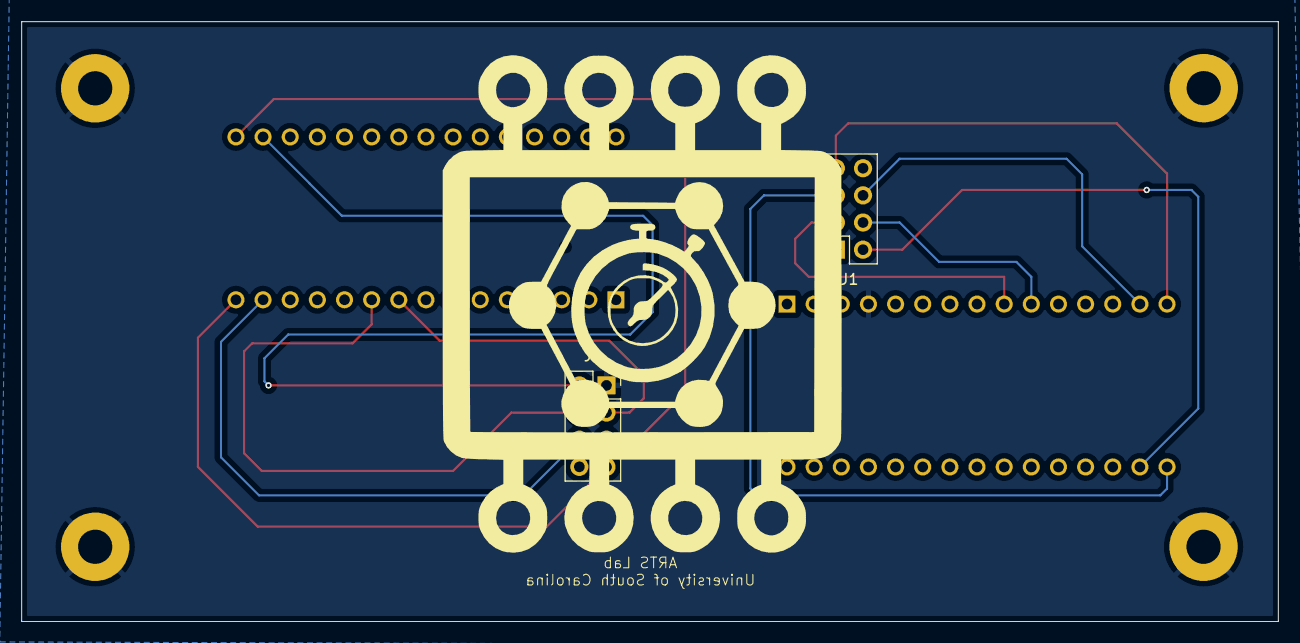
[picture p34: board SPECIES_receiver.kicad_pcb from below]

Board: 2 copper layers, 117.6 x 56.1 mm, 10 parts (2 on the bottom side), 8 nets.

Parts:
A1: Nano 1; Arduino_Nano
A2: Nano 2; Arduino_Nano
C1 - 100uF, C2 - 10uF, C3 - 1uF, C4 - 100uF, C5 - 10uF, C6 - 1uF: C_Small; C_1206_3216Metric
J1, J2: Conn_02x04_Odd_Even_MountingPin; PinSocket_2x04_P2.54mm_Vertical

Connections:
3V3: A1.17 (3V3), A2.17 (3V3), C1 - 100uF.1, C2 - 10uF.1, C3 - 1uF.1, C4 - 100uF.1, C5 - 10uF.1, C6 - 1uF.1, J1.2, J2.2
CE: A1.9 (D6), A2.9 (D6), J1.3, J2.3
CLK: A1.16 (D13), A2.16 (D13), J1.5, J2.5
CSN: A1.10 (D7), A2.10 (D7), J1.4, J2.4
GND: A1.4 (GND), A2.4 (GND), C1 - 100uF.2, C2 - 10uF.2, C3 - 1uF.2, C4 - 100uF.2, C5 - 10uF.2, C6 - 1uF.2, J1.1, J2.1
MISO: A1.15 (D12), A2.15 (D12), J1.7, J2.7
MOSI: A1.14 (D11), A2.14 (D11), J1.6, J2.6
unnamed: A2.27 (+5V), A2.30 (VIN)

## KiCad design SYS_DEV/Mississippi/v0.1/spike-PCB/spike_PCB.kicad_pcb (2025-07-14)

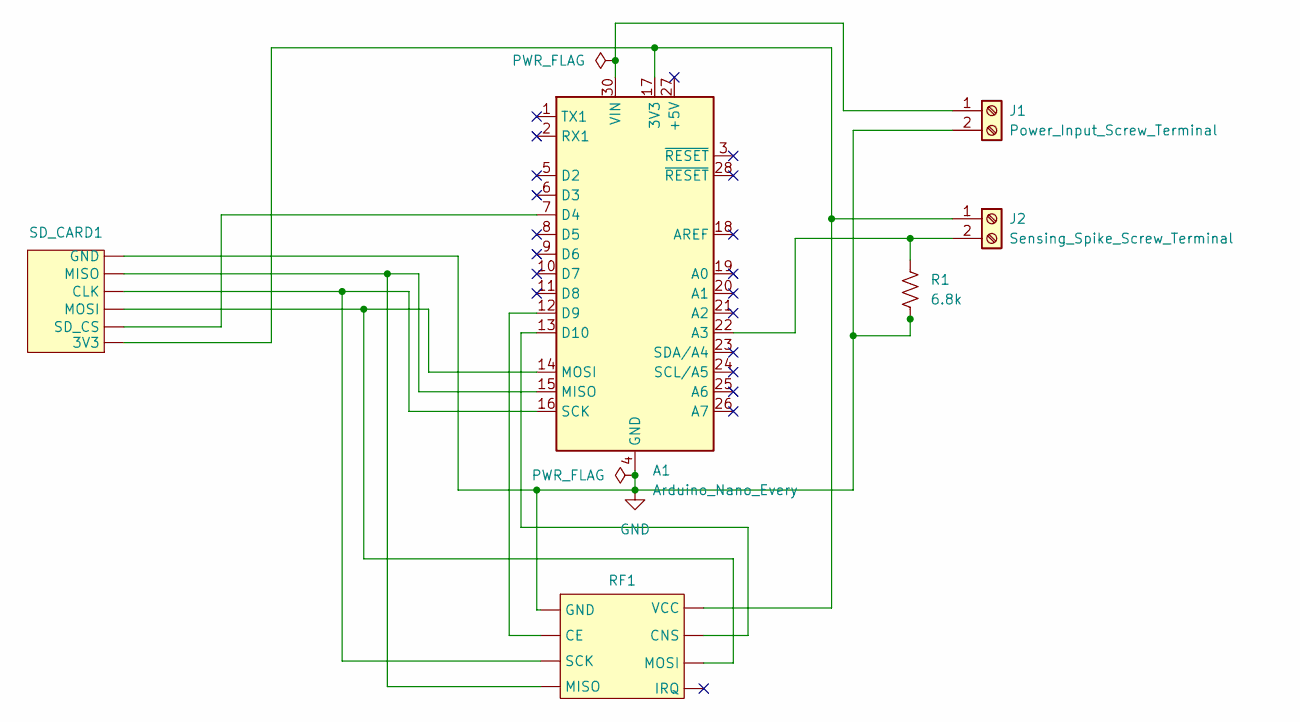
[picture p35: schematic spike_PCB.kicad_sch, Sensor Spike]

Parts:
A1: Arduino_Nano_Every; Arduino_Nano
J1: Power_Input_Screw_Terminal; TerminalBlock_Altech_AK300-2_P5.00mm
J2: Sensing_Spike_Screw_Terminal; TerminalBlock_Altech_AK300-2_P5.00mm
R1: 6.8k; R_Axial_DIN0207_L6.3mm_D2.5mm_P7.62mm_Horizontal
RF1: nRF24L01
SD_CARD1: SD_Card_Module

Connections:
GND: A1.4 (GND), A1.29 (GND), J1.2, R1.2, RF1.1 (GND), SD_CARD1.6 (GND)
unnamed: A1.17 (3V3), J2.1, RF1.5 (VCC), SD_CARD1.1 (3V3)
unnamed: A1.22 (A3), J2.2, R1.1
unnamed: A1.7 (D4), SD_CARD1.2 (SD_CS)
unnamed: A1.12 (D9), RF1.2 (CE)
unnamed: A1.13 (D10), RF1.6 (CNS)
unnamed: A1.15 (MISO), RF1.4 (MISO), SD_CARD1.5 (MISO)
unnamed: A1.14 (MOSI), RF1.7 (MOSI), SD_CARD1.3 (MOSI)
unnamed: A1.16 (SCK), RF1.3 (SCK), SD_CARD1.4 (CLK)
unnamed: A1.30 (VIN), J1.1

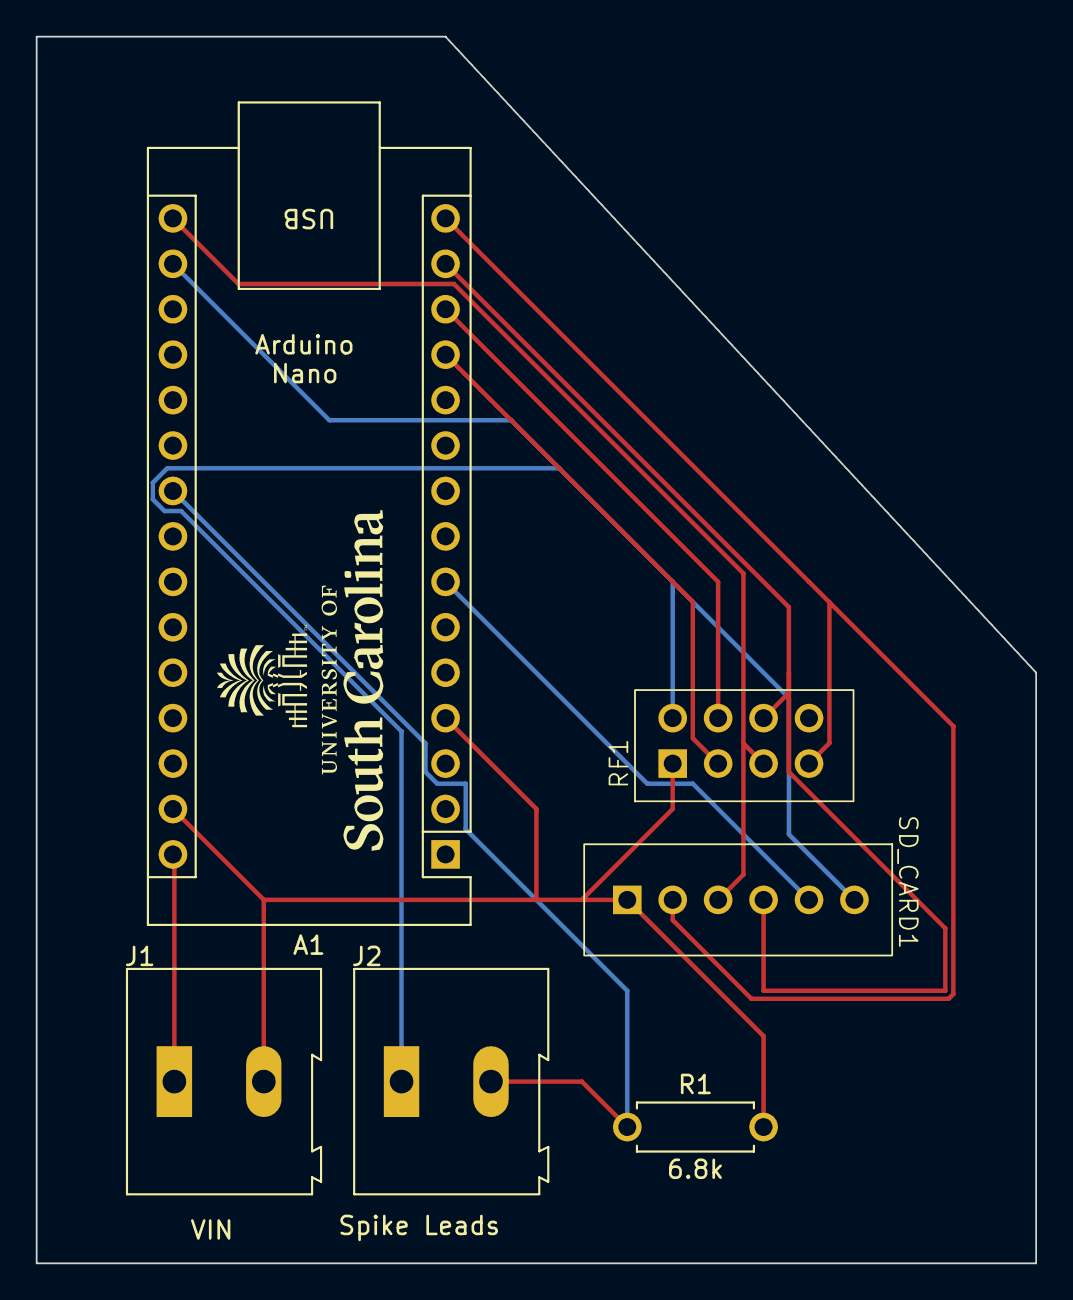
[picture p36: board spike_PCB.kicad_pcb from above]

Board: 2 copper layers, 55.9 x 68.6 mm, 6 parts (0 on the bottom side), 10 nets.

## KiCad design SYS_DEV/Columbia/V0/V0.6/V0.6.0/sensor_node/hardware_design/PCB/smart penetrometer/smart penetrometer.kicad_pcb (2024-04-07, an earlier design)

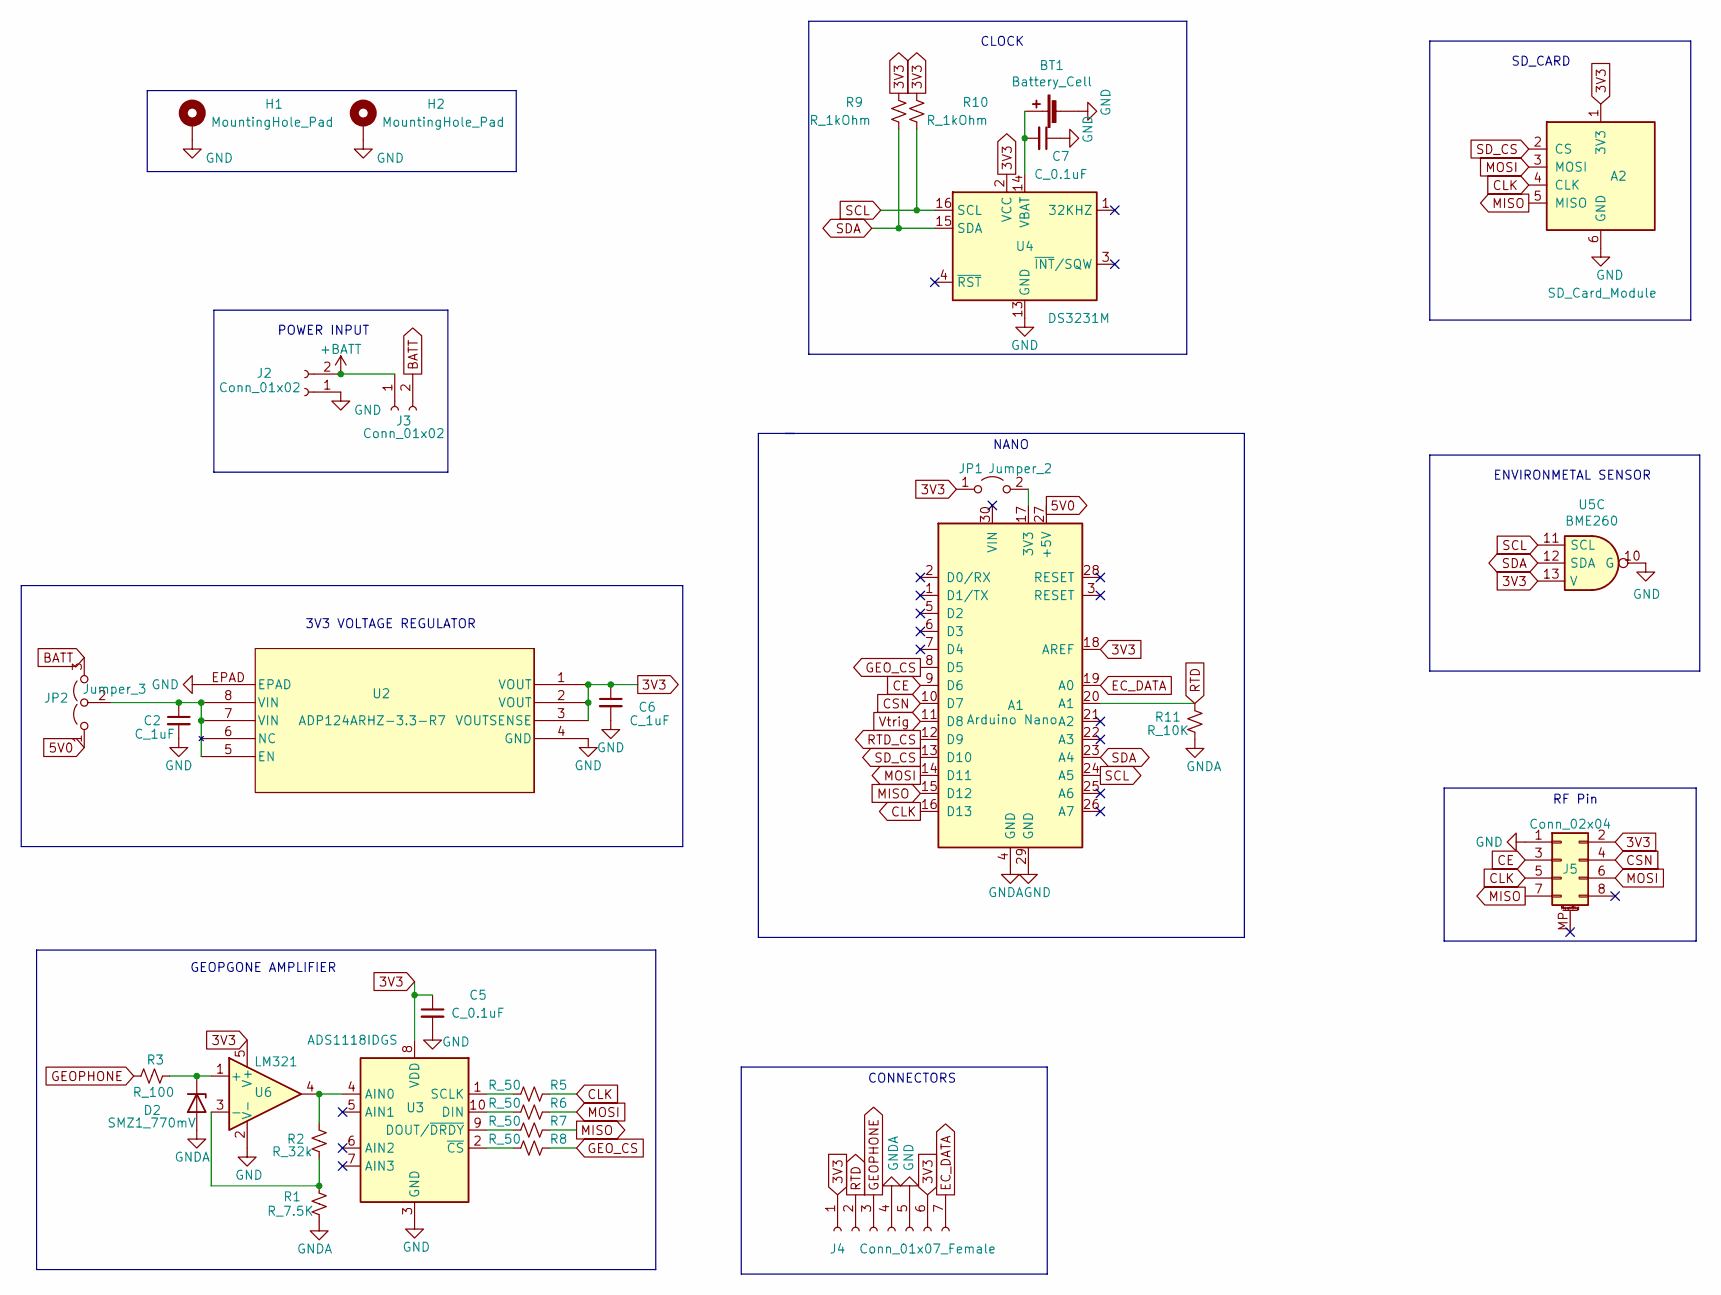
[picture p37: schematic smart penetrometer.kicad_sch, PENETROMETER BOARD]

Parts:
A1: Arduino Nano; Arduino_Nano
A2: SD_Card_Module; SD Module
BT1: Battery_Cell; battery_holder_10mm
C2, C6: C_1uF; C_1206_3216Metric
C5, C7: C_0.1uF; C_1206_3216Metric
D2: SMZ1_770mV; D_MELF
H1, H2: MountingHole_Pad; MountingHole_3.2mm_M3_Pad
J2, J3: Conn_01x02; PinSocket_1x02_P2.54mm_Horizontal
J4: Conn_01x07_Female; PinSocket_1x07_P2.54mm_Horizontal
J5: Conn_02x04; PinSocket_2x04_P2.54mm_Vertical
JP1: Jumper_2; PinHeader_1x02_P2.54mm_Vertical
JP2: Jumper_3; PinHeader_1x03_P2.54mm_Vertical
R1: R_7.5K; R_1206_3216Metric
R2: R_32k; R_1206_3216Metric
R3: R_100; R_1206_3216Metric
R5, R6, R7, R8: R_50; R_1206_3216Metric
R9, R10: R_1kOhm; R_1206_3216Metric
R11: R_10K; R_1206_3216Metric
U2: ADP124ARHZ-3.3-R7; RH_8_1_ADI
U3: ADS1118IDGS; ADS1118_10VSSOP
U4: DS3231M; SOIC-16W_7.5x10.3mm_P1.27mm
U5: BME260
U6: LM321; SOT-23-5

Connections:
3V3: A1.18 (AREF), A2.1 (3V3), C5.1, C6.1, J4.1, J4.6, J5.2, JP1.1 (A), R9.1, R10.1, U2.1 (VOUT), U2.2 (VOUT), U2.3 (VOUTSENSE), U3.8 (VDD), U4.2 (VCC), U5.13, U6.5 (V+)
5V0: A1.27 (+5V), JP2.1 (A)
+BATT: J2.2, J3.1
BATT: J3.2, JP2.3 (B)
CE: A1.9 (D6), J5.3
CLK: A1.16 (D13), A2.4 (CLK), J5.5, R5.1
CSN: A1.10 (D7), J5.4
EC_DATA: A1.19 (A0), J4.7
GEOPHONE: J4.3, R3.1
GEO_CS: A1.8 (D5), R8.1
GND: A1.29 (GND), A2.6 (GND), BT1.2 (-), C2.2, C5.2, C6.2, C7.1, H1.1, H2.1, J2.1, J4.5, J5.1, U2.4 (GND), U2.EPAD, U3.3 (GND), U4.5 (GND), U4.6 (GND), U4.7 (GND), U4.8 (GND), U4.9 (GND), U4.10 (GND), U4.11 (GND), U4.12 (GND), U4.13 (GND), U5.10, U6.2 (V-)
GNDA: A1.4 (GND), D2.2 (A), J4.4, R1.2, R11.2
MISO: A1.15 (D12), A2.5 (MISO), J5.7, R7.1
MOSI: A1.14 (D11), A2.3 (MOSI), J5.6, R6.1
unnamed: A1.17 (3V3), JP1.2 (B)
unnamed: BT1.1 (+), C7.2, U4.14 (VBAT)
unnamed: D2.1 (K), R3.2, U6.1 (+)
unnamed: C2.1, JP2.2 (C), U2.5 (EN), U2.7 (VIN), U2.8 (VIN)
unnamed: R2.1, U3.4 (AIN0), U6.4
unnamed: R6.2, U3.10 (DIN)
unnamed: R7.2, U3.9 (DOUT/~DRDY)
unnamed: R5.2, U3.1 (SCLK)
unnamed: R8.2, U3.2 (~CS)
unnamed: R1.1, R2.2, U6.3 (-)
RTD: A1.20 (A1), J4.2, R11.1
RTD_CS: A1.12 (D9)
SCL: A1.24 (A5), R10.2, U4.16 (SCL), U5.11
SDA: A1.23 (A4), R9.2, U4.15 (SDA), U5.12
SD_CS: A1.13 (D10), A2.2 (CS)
Vtrig: A1.11 (D8)

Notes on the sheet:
GEOPGONE AMPLIFIER
POWER INPUT
3V3 VOLTAGE REGULATOR
NANO
CLOCK
RF Pin
CONNECTORS
SD_CARD
ENVIRONMETAL SENSOR

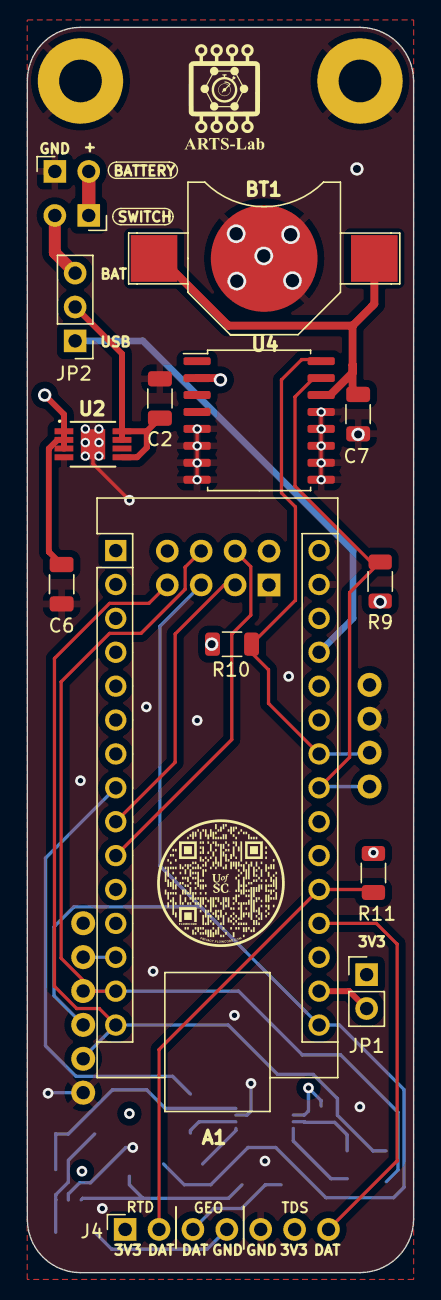
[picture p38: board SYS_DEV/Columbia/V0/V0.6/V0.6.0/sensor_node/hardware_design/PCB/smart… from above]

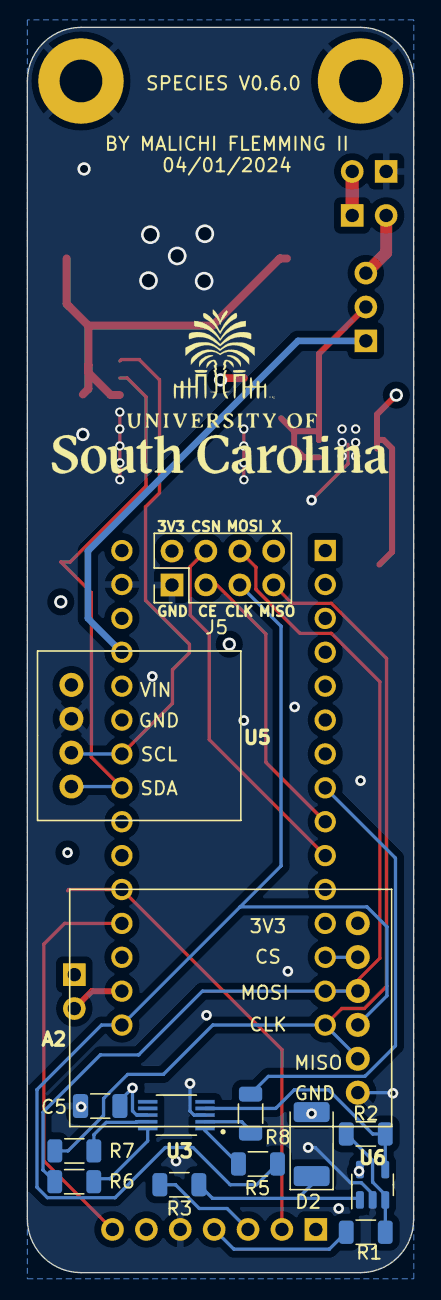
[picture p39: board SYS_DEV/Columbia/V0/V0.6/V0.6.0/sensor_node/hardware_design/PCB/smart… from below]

Board: 4 copper layers, 29.0 x 93.3 mm, 31 parts (13 on the bottom side), 28 nets.

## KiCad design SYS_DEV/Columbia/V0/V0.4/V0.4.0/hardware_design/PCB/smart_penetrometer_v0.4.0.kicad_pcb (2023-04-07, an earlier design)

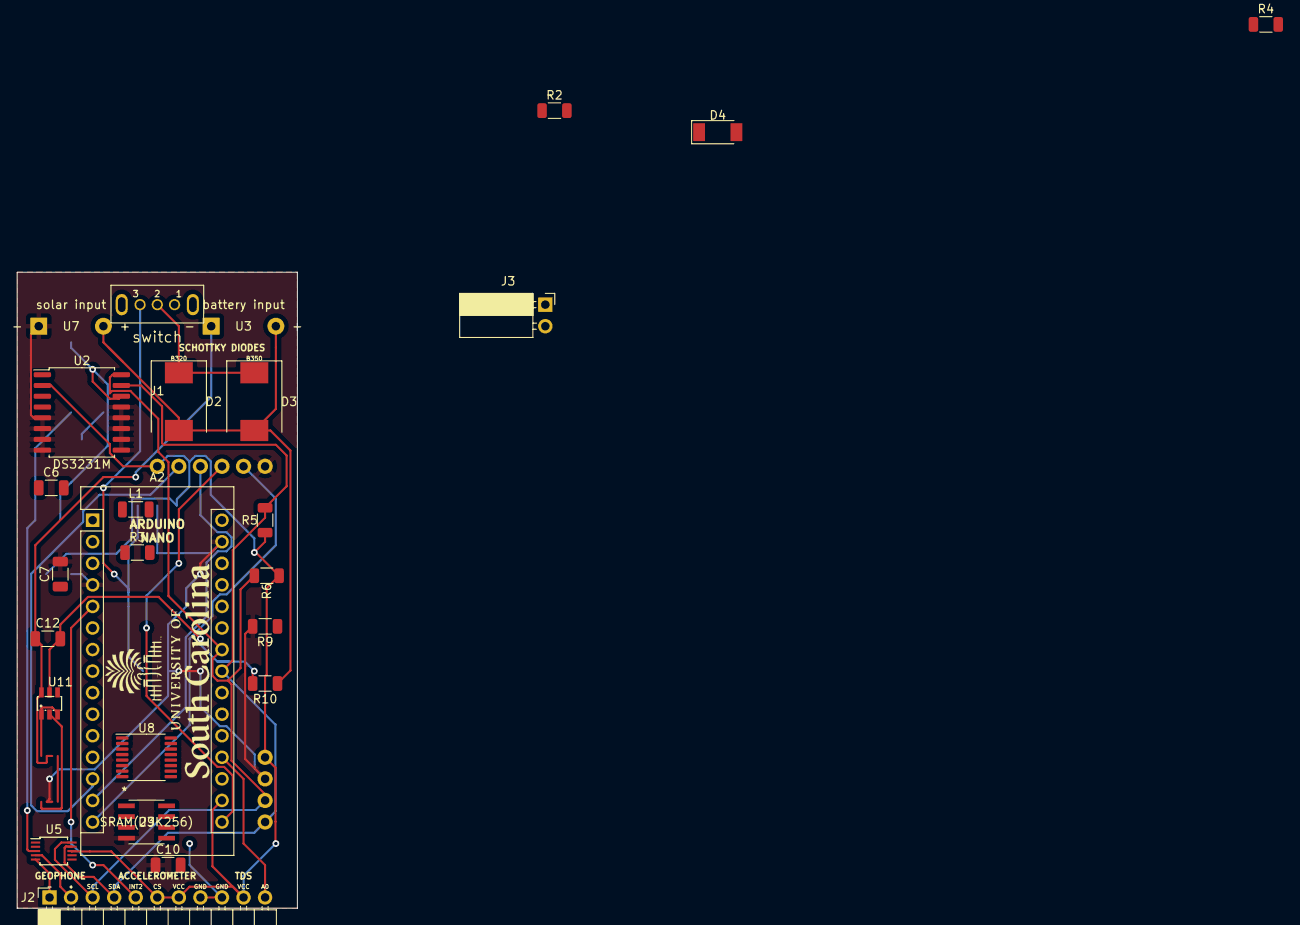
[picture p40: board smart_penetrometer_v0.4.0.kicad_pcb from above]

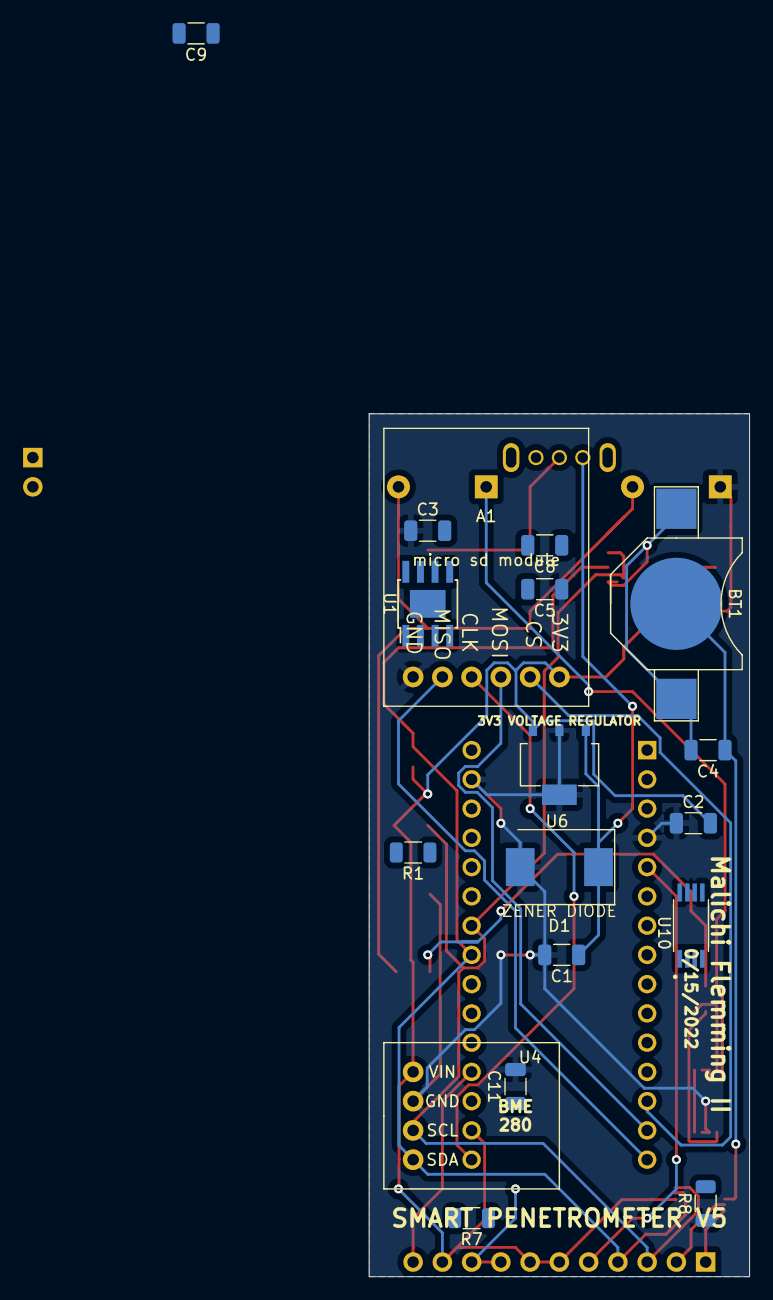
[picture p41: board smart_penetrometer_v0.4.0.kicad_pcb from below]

Board: 2 copper layers, 33.0 x 74.9 mm, 45 parts (18 on the bottom side), 35 nets.

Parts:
A1: SD_Card_Module; SD Module
A2: Arduino_Nano_v3.x; Arduino_Nano
BT1: Battery_Cell; battery_holder_10mm
C1, C9, C10, C11: C_0.1uF; C_1206_3216Metric
C2, C3, C8: C_10uF; C_1206_3216Metric
C4: C_Small; C_1206_3216Metric
C5, C7: C_0.047uF; C_1206_3216Metric
C6: C_0.47uF; C_1206_3216Metric
C12: CP1_Small; C_1206_3216Metric
D1: D_Zener_Small; D_SMC
D2: B320; D_SMC
D3: B350; D_SMC
D4: PMEG6045ETP; D_SOD-128
J1: XLR3_Switched; grounded_switch
J2: Conn_01x11_Female; PinSocket_1x11_P2.54mm_Horizontal
J3: Conn_01x02_Female; PinSocket_1x02_P2.54mm_Horizontal
L1: L; L_1206_3216Metric
R1, R2: R_1MOhm; R_1206_3216Metric
R3, R4: R_800Ohm; R_1206_3216Metric
R5, R6, R7, R8, R9, R10: R_Small_US; R_1206_3216Metric
U1: 4001; uofsc_logo_1in
U1#2: LM22676MR-5; TI_SO-PowerPAD-8
U2: DS3231M; SOIC-16W_7.5x10.3mm_P1.27mm
U3: Battery_Input
U4: 4023; TDS_module
U5: ADS1115IDGS; TSSOP-10_3x3mm_P0.5mm
U6: 3v3_Voltage_Regulator; BD433M2FP3_CE2
U7: Solar_Input; Battery_Input
U8: ADS1120-PW; TSSOP-16_4.4x5mm_P0.65mm
U9: SRAM(23K256); 23K256T-E&slash_SN
U10: FS8205A; DUAL_MOSFET(FS8205A)
U11: DW01; BATTERY_PROTECTION_IC(DW01A)

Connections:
+BATT: D2.2, D3.2, R10.1, U3.1, U7.1
-BATT: C12.1, U3.2, U10.2, U10.3, U11.6
GND: A1.6, A2.4, A2.29, C1.2, C2.1, C3.1, C5.1, C7.2, C9.2, C10.1, C11.2, D1.2, D4.2, R2.2, R8.1, R9.2, U1#2.6, U2.5, U2.6, U2.7, U2.8, U2.9, U2.10, U2.11, U2.12, U2.13, U4.10, U6.2, U6.4, U7.2, U8.3, U8.5, U9.4, U10.6, U10.7
GNDREF: J2.8, J2.9
GNDS: BT1.2, C4.1, U5.3
unnamed: A1.1, A2.30, C2.2, C9.1, C11.1, J2.6, J2.7, J2.10, R1.1, R5.1, R6.1, U2.2, U4.13, U5.8, U6.3, U8.12, U8.13, U9.8
unnamed: A1.2, A2.13
unnamed: A1.3, A2.14, U8.16, U9.5
unnamed: A1.4, A2.16, U8.1, U9.6
unnamed: A1.5, A2.15, U8.15, U9.2
unnamed: A2.5, J2.5
unnamed: A2.10, U9.7
unnamed: A2.11, U9.1
unnamed: A2.12, U8.2
unnamed: A2.19, J2.11
unnamed: A2.23, J2.4, R5.2, U2.15, U4.12, U5.9
unnamed: A2.24, J2.3, R6.2, U2.16, U4.11, U5.10
unnamed: BT1.1, C4.2, U2.14
unnamed: C1.1, C10.2, D1.1, L1.1, R7.1, U6.1
unnamed: C3.2, J1.3, U1#2.7
unnamed: C5.2, C6.1, R3.1, U8.11
unnamed: C6.2, C7.1, R4.1, U8.10
unnamed: C8.1, D4.1, L1.2, U1#2.8
unnamed: C8.2, U1#2.1
unnamed: C12.2, R10.2, U11.5
unnamed: D2.1, D3.1, J1.2
unnamed: J2.1, U5.5
unnamed: J2.2, U5.4
unnamed: J3.1, R2.1, R4.2
unnamed: J3.2, R1.2, R3.2
unnamed: R7.2, R8.2, U1#2.4
unnamed: R9.1, U11.2
unnamed: U10.1, U10.8
unnamed: U10.4, U11.1
unnamed: U10.5, U11.3

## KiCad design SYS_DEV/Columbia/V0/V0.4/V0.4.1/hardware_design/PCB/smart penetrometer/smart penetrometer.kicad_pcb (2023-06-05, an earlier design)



Board: 4 copper layers, 29.0 x 83.8 mm, 25 parts (5 on the bottom side), 23 nets.

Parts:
A1: Arduino_Nano_v3.x; Arduino_Nano
A2: SD_Card_Module; SD Module
BT1: Battery_Cell; battery_holder_10mm
C1, C3: C_0.047uF; C_1206_3216Metric
C2: C_0.47uF; C_1206_3216Metric
C4, C5: C_0.1uF; C_1206_3216Metric
C6: C_Small; C_1206_3216Metric
J1: Conn_01x02_Female; PinSocket_1x02_P2.54mm_Horizontal
J2: XLR3_Switched; grounded_switch
J3: Conn_01x07_Female; PinSocket_1x07_P2.54mm_Horizontal
J4: Screw_Terminal; TerminalBlock_bornier-2_P5.08mm
R1, R2: R_1MOhm; R_1206_3216Metric
R3, R4: R_800Ohm; R_1206_3216Metric
R5, R6: R_Small_US; R_1206_3216Metric
R7: R_1.9kOhm; R_1206_3216Metric
U1: ADS1120-PW; VQFN-16-1EP_3x3mm_P0.5mm_EP1.45x1.45mm_ThermalVias
U2: DS3231M; SOIC-16W_7.5x10.3mm_P1.27mm
U3: 4023; TDS_module
U4: ADS1115IDGS; 10X2QFN
U5: VO615A; Vishay_VOS615A

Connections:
3V3: A1.17 (3V3), A2.1 (3V3), C4.1, C5.1, J3.6, R1.1, R5.1, R6.1, U1.10 (AVDD), U1.11 (DVDD), U2.2 (VCC), U3.13, U4.8 (VDD)
5V0: A1.11 (D8), A1.27 (+5V), U5.4
CLK: A1.16 (D13), A2.4 (CLK), U1.15 (SCLK)
EC_DATA: A1.19 (A0), J3.7
GEO_AMP_0: J3.3, U4.4 (AIN0)
GEO_AMP_1: J3.4, U4.5 (AIN1)
GND: A1.4 (GND), A1.29 (GND), A2.6 (GND), BT1.2 (-), C1.1, C3.2, C4.2, C5.2, C6.1, J1.1, J3.5, R2.2, R7.2, U1.1 (CLK), U1.2 (DGND), U1.3 (AVSS), U1.17 (thermal), U2.5 (GND), U2.6 (GND), U2.7 (GND), U2.8 (GND), U2.9 (GND), U2.10 (GND), U2.11 (GND), U2.12 (GND), U2.13 (GND), U3.10, U4.3 (GND)
MISO: A1.15 (D12), A2.5 (MISO), U1.13 (DOUT/~DRDY)
MOSI: A1.14 (D11), A2.3 (MOSI), U1.14 (DIN)
unnamed: BT1.1 (+), C6.2, U2.14 (VBAT)
unnamed: C1.2, C2.1, R3.1, U1.9 (AIN0/REFP1)
unnamed: C2.2, C3.1, R4.1, U1.8 (AIN1)
unnamed: J4.1, U5.1
unnamed: J4.2, U5.2
unnamed: R7.1, U5.3
POWER: J1.2, J2.1
SCL: A1.24 (A5), R6.2, U2.16 (SCL), U3.11, U4.10 (SCL)
SDA: A1.23 (A4), R5.2, U2.15 (SDA), U3.12, U4.9 (SDA)
SD_CS: A1.13 (D10), A2.2 (CS)
TEMP_AMP_0: J3.2, R1.2, R3.2
TEMP_AMP_1: J3.1, R2.1, R4.2
TEMP_AMP_CS: A1.12 (D9), U1.16 (~CS)
VIN: A1.30 (VIN), J2.2

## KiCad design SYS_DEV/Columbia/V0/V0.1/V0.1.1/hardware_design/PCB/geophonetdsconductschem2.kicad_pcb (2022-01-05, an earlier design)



Board: 2 copper layers, 33.0 x 73.7 mm, 22 parts (16 on the bottom side), 19 nets.

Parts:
A1: SD_Card_Module; SD Module
A2: Arduino_Nano_v3.x; Arduino_Nano
BT1: Battery_Cell; battery_holder_10mm
C1, C2, C3, C4: C_Small; C_1206_3216Metric
J1: XLR3_Switched; grounded_switch
J2: Conn_01x03_Female; PinSocket_1x03_P2.54mm_Horizontal
J3: Conn_01x02_Female; PinSocket_1x02_P2.54mm_Horizontal
J4: Conn_01x04_Female; PinSocket_1x04_P2.54mm_Horizontal
R1, R2, R3, R4, R5, R6: R_Small_US; R_1206_3216Metric
U1: LMV324; LMV324IDR
U2: DS3231M; SOIC-16W_7.5x10.3mm_P1.27mm
U3: Battery_Input
U4: 4023; TDS_module
U5: ADS1115IDGS; TSSOP-10_3x3mm_P0.5mm

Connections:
GND: A1.6, A2.4, A2.29, C1.2, C2.2, J2.1, R2.2, U1.11, U2.5, U2.6, U2.7, U2.8, U2.9, U2.10, U2.11, U2.12, U2.13, U3.2, U4.10
GNDS: BT1.2, C3.1, C4.1, J4.1, U5.3
unnamed: A1.1, A2.17, C1.1, C3.2, J2.2, J4.2, R1.1, R5.1, R6.1, U1.4, U2.2, U4.13
unnamed: A1.2, A2.13
unnamed: A1.3, A2.14
unnamed: A1.4, A2.16
unnamed: A1.5, A2.15
unnamed: A2.19, J2.3
unnamed: A2.20, U5.4
unnamed: A2.23, J4.3, R5.2, U2.15, U4.12, U5.9
unnamed: A2.24, J4.4, R6.2, U2.16, U4.11, U5.10
unnamed: A2.30, J1.3
unnamed: BT1.1, C4.2, U2.14
unnamed: C2.1, R1.2, R2.1, U1.5
unnamed: J3.1, R4.2, U1.6, U1.7
unnamed: J3.2, U1.3
unnamed: R3.1, U1.1, U5.8
unnamed: R3.2, R4.1, U1.2
VCC: J1.2, U3.1

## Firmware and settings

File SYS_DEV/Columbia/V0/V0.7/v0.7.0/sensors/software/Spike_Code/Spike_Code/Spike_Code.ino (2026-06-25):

//@author: Malichi Flemming II

// TRANSMITTER: struct-based RF24 + CRC + counter + watchdog + sleep

#include <Wire.h>
#include "RTClib.h"
#include <SPI.h>
#include <SD.h>
#include <nRF24L01.h>
#include <RF24.h>
#include <BMx280I2C.h>
#include <Adafruit_ADS1X15.h>
#include <EEPROM.h>
#include <avr/sleep.h>
#include <avr/wdt.h>
#include <math.h>
#include <stdint.h>

// -------------------- PINS --------------------
#define OE_PIN A0
#define EN_3V3 5
#define RTC_INT_PIN 3
#define NODE_ID 3

// -------------------- OBJECTS -----------------
RTC_DS3231 rtc;
BMx280I2C bmx280(0x76);
RF24 radio(6, 7);
Adafruit_ADS1115 ads;

extern int __heap_start, *__brkval;
int freeRam() {
  int v;
  return (int)&v - (__brkval == 0 ? (int)&__heap_start : (int)__brkval);
}
// -------------------- RADIO ADDRESSES --------
const byte Address[6][6] = {
  "1node", "2node", "3node", "4node", "5node", "6node"
};

// -------------------- PACKETS -----------------
// 32-byte packed data packet
struct DataPacket {
  uint8_t type;      // 1
  uint8_t nodeId;    // 1
  uint16_t counter;  // 2

  int16_t rtdTemp;        // 2  (°C × 100)
  int16_t bmeTemp;        // 2  (°C × 100)
  uint16_t humidity;      // 2  (% × 100)
  uint16_t pressure;      // 2  (hPa)
  uint16_t conductivity;  // 2  (scaled ×100)
  uint16_t battery;       // 2  (V × 1000)

  uint32_t time;  // 4  (ms)
  uint32_t crc;   // 4  (CRC32 over first 28 bytes)
};                // TOTAL = 32 bytes

// -------------------- CRC32 -------------------
uint32_t crc32_update(uint32_t crc, uint8_t data) {
  crc ^= data;
  for (uint8_t i = 0; i < 8; i++) {
    if (crc & 1) crc = (crc >> 1) ^ 0xEDB88320UL;
    else crc >>= 1;
  }
  return crc;
}

template<typename T>
uint32_t crc32_calc(const T& obj, size_t lenWithoutCRC) {
  const uint8_t* p = (const uint8_t*)&obj;
  uint32_t crc = 0xFFFFFFFFUL;
  for (size_t i = 0; i < lenWithoutCRC; i++) {
    crc = crc32_update(crc, p[i]);
  }
  return ~crc;
}

// -------------------- GLOBALS -----------------
volatile bool rtcWake = true;
uint8_t wakeIntervalMin = 1;  // default 1 minute
uint16_t pktCounter = 0;
volatile uint8_t wdtCounter = 0;

// -------------------- ISR ---------------------
void ISR_RTC() {
  rtcWake = true;
}

ISR(WDT_vect) {
  wdtCounter++;
}
void forceReset() {
  cli();                  // disable interrupts
  wdt_enable(WDTO_15MS);  // shortest timeout
  while (1) {}            // wait for watchdog to reset MCU
}

// -------------------- HELPERS -----------------
uint8_t decToBcd(uint8_t v) {
  return ((v / 10) << 4) | (v % 10);
}
uint8_t bcdToDec(uint8_t v) {
  return (v >> 4) * 10 + (v & 0x0F);
}
void setAlarm1_60sec() {
  DateTime now = rtc.now();
  DateTime next = now + TimeSpan(60);  // EXACT 60 seconds later

  // Program Alarm1 for exact second match
  Wire.beginTransmission(0x68);
  Wire.write(0x07);  // Alarm1 registers start

  Wire.write(decToBcd(next.second()));  // A1M1 = 0
  Wire.write(decToBcd(next.minute()));  // A1M2 = 0
  Wire.write(decToBcd(next.hour()));    // A1M3 = 0
  Wire.write(decToBcd(next.day()));     // A1M4 = 0 (date match)

  Wire.endTransmission();

  // Enable Alarm1 interrupt
  Wire.beginTransmission(0x68);
  Wire.write(0x0E);        // control register
  Wire.write(0b00000101);  // INTCN=1, A1IE=1
  Wire.endTransmission();
}


void loadWakeInterval() {
  uint8_t v = EEPROM.read(0);
  if (v == 0xFF || v == 0) v = 1;
  wakeIntervalMin = v;
}

float rtdTempFromR(float R) {
  const float R0 = 1000.0;
  const float A = 3.9083e-3;
  const float B = -5.775e-7;
  float ratio = R / R0;
  float disc = A * A - 4 * B * (1 - ratio);
  if (disc < 0) return -999;
  return (-A + sqrt(disc)) / (2 * B);
}

float readBatteryVoltage() {
  float v = ads.computeVolts(ads.readADC_SingleEnded(2));
  return v * 2.0;
}

void enterSleep() {
  cli();
  // Enable watchdog interrupt mode (not reset mode)
  WDTCSR = (1 << WDCE) | (1 << WDE);   // enable config
  WDTCSR = (1 << WDIE) | (1 << WDP3);  // interrupt mode, ~8s timeout
  sei();                               // re-enable interrupts BEFORE sleeping
  delay(10);
  rtcWake = false;
  digitalWrite(OE_PIN, HIGH);
  digitalWrite(EN_3V3, LOW);
  set_sleep_mode(SLEEP_MODE_PWR_DOWN);
  sleep_enable();
  sleep_cpu();
  sleep_disable();
}

void wakeFromSleep() {
  wdtCounter = 0;  // RTC woke successfully

  // Power sensors and peripherals
  // Serial.println("WAKE_FROM_SLEEP");
  Serial.flush();
  digitalWrite(EN_3V3, HIGH);
  delay(200);
  // Serial.println("a");
  Wire.begin();
  delay(10);
  // Serial.println("b");
  SPI.begin();
  delay(5);
  // Serial.println("c");
  radio.powerUp();
  delay(5);
  // Serial.println("d");
  SD.begin(10);
  delay(10);
  // Serial.println("e");
  // if (!ads.begin()) {
  //   Serial.println("ADS1115 FAILED");
  // } else {
  //   delay(10);
  // }

  if (!bmx280.begin()) {
    Serial.println("BME280 FAILED");
  } else {
    bmx280.resetToDefaults();
    bmx280.writeOversamplingPressure(BMx280MI::OSRS_P_x16);
    bmx280.writeOversamplingTemperature(BMx280MI::OSRS_T_x16);
    bmx280.writeOversamplingHumidity(BMx280MI::OSRS_H_x16);
    delay(10);
  }
  // Serial.println("f");
  // Clear alarm flags properly
  Wire.beginTransmission(0x68);
  Wire.write(0x0F);
  Wire.endTransmission();

  Wire.requestFrom(0x68, 1);
  uint8_t status = Wire.read();

  status &= ~0b00000001;  // clear A1F only

  Wire.beginTransmission(0x68);
  Wire.write(0x0F);
  Wire.write(status);
  Wire.endTransmission();
  setAlarm1_60sec();

  // Serial.println("g");
  wdt_enable(WDTO_8S);
}

void doMeasurementCycle() {
  wdt_reset();
  // Serial.println("measure");
  if (!bmx280.begin()) {
    bmx280.resetToDefaults();
    bmx280.writeOversamplingPressure(BMx280MI::OSRS_P_x16);
    bmx280.writeOversamplingTemperature(BMx280MI::OSRS_T_x16);
    bmx280.writeOversamplingHumidity(BMx280MI::OSRS_H_x16);
  }

  float vref = ads.computeVolts(ads.readADC_SingleEnded(2));

  float vRTD = ads.computeVolts(ads.readADC_SingleEnded(0));
  float r1 = (10000.0f * (vref - vRTD)) / vRTD;
  float rtdT = rtdTempFromR(r1);

  bmx280.measure();
  unsigned long startWait = millis();
  while (!bmx280.hasValue()) {
    if (millis() - startWait > 500) break;
  }

  float bmeT = bmx280.getTemperature();
  float hum = bmx280.getHumidity();
  float pres = bmx280.getPressure64() / 100.0F;

  float condV = ads.computeVolts(ads.readADC_SingleEnded(3));
  float cond = 2.6671f * condV + 0.0535f;
  if (cond < 0) cond = 0;

  float batt = readBatteryVoltage();
  uint32_t tms = millis();

  DataPacket pkt;
  pkt.type = 0x01;
  pkt.nodeId = NODE_ID;
  pkt.counter = ++pktCounter;

  pkt.rtdTemp = (int16_t)(rtdT * 100.0f);
  pkt.bmeTemp = (int16_t)(bmeT * 100.0f);
  pkt.humidity = (uint16_t)(hum * 100.0f);
  pkt.pressure = (uint16_t)(pres);
  pkt.conductivity = (uint16_t)(cond * 100.0f);
  pkt.battery = (uint16_t)(batt * 1000.0f);

  pkt.time = tms;

  pkt.crc = crc32_calc(pkt, sizeof(DataPacket) - sizeof(uint32_t));

  // Serial.print("Sending size = ");
  // Serial.println(sizeof(pkt));
  // Serial.println("SENDING NOW");

  bool ok = radio.write(&pkt, sizeof(pkt));
  delay(5);

  // Serial.print("radio.write ok = ");
  // Serial.println(ok ? "true" : "false");
  // delay(5);
  // Local SD logging (decoded back to floats for readability)
  File f = SD.open("node3.txt", FILE_WRITE);
  if (f) {
    float rtdT_f = pkt.rtdTemp / 100.0f;
    float bmeT_f = pkt.bmeTemp / 100.0f;
    float hum_f = pkt.humidity / 100.0f;
    float pres_f = pkt.pressure;
    float cond_f = pkt.conductivity / 100.0f;
    float batt_f = pkt.battery / 1000.0f;

    f.print(pkt.nodeId);
    f.print(" ");
    f.print(pkt.counter);
    f.print(" ");
    f.print(pkt.time);
    f.print(" ");
    f.print(rtdT_f, 4);
    f.print(" ");
    f.print(bmeT_f, 4);
    f.print(" ");
    f.print(hum_f, 4);
    f.print(" ");
    f.print(pres_f, 4);
    f.print(" ");
    f.print(cond_f, 4);
    f.print(" ");
    f.println(batt_f, 4);
    f.close();
  }

  wdt_reset();
}

// -------------------- SETUP / LOOP -----------
void setup() {
  MCUSR = 0;
  wdt_disable();

  Serial.begin(115200);
  Serial.print("TX DataPacket size = ");
  Serial.println(sizeof(DataPacket));
  Wire.begin();

  pinMode(OE_PIN, OUTPUT);
  pinMode(EN_3V3, OUTPUT);
  pinMode(RTC_INT_PIN, INPUT_PULLUP);

  digitalWrite(EN_3V3, HIGH);
  digitalWrite(OE_PIN, LOW);

  attachInterrupt(digitalPinToInterrupt(RTC_INT_PIN), ISR_RTC, FALLING);

  if (!rtc.begin()) {
    Serial.println("RTC failed");
    while (1)
      ;
  }

  rtc.clearAlarm(1);
  rtc.clearAlarm(2);

  if (!ads.begin()) {
    Serial.println("ADS failed");
    while (1)
      ;
  }

  if (!bmx280.begin()) {
    Serial.println("BME failed");
    while (1)
      ;
  }
  bmx280.resetToDefaults();
  bmx280.writeOversamplingPressure(BMx280MI::OSRS_P_x16);
  bmx280.writeOversamplingTemperature(BMx280MI::OSRS_T_x16);
  bmx280.writeOversamplingHumidity(BMx280MI::OSRS_H_x16);

  SD.begin(10);

  radio.begin();
  delay(100);
  radio.setDataRate(RF24_250KBPS);
  radio.setPALevel(RF24_PA_LOW);
  radio.setChannel(108);
  radio.disableDynamicPayloads();
  radio.disableAckPayload();
  radio.setAutoAck(true);
  radio.setPayloadSize(32);
  radio.setCRCLength(RF24_CRC_16);
  radio.stopListening();
  radio.openWritingPipe(Address[NODE_ID - 1]);
  radio.setRetries(5, 15);
  setAlarm1_60sec();


  wdt_enable(WDTO_8S);
}

void loop() {
  // If watchdog fired too many times without RTC wake → RTC FAILED
  if (!rtcWake) {
    Serial.println(wdtCounter);
    if (wdtCounter >= 14) {  // 9 × 8s = 72seconds
      Serial.println("RTC FAILED — FORCING RESET");
      forceReset();
    }
  }

  delay(200);
  if (rtcWake) {
    // Serial.print("RAM at loop start: ");
    // Serial.println(freeRam());
    wakeFromSleep();
    doMeasurementCycle();
    enterSleep();
    // wdt_reset();
  }
}

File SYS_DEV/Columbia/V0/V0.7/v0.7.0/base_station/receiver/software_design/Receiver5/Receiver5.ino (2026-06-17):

#include <SPI.h>
#include <nRF24L01.h>
#include <RF24.h>
#include <SD.h>
#include <stdint.h>

// -------------------- PINS --------------------
#define CE_PIN  6
#define CSN_PIN 7

RF24 radio(CE_PIN, CSN_PIN);

// -------------------- ADDRESSES ---------------
const byte pipes[6][6] = {
  "1node","2node","3node","4node","5node","6node"
};

// -------------------- PACKETS -----------------
struct DataPacket {
  uint8_t  type;
  uint8_t  nodeId;
  uint16_t counter;

  int16_t  rtdTemp;
  int16_t  bmeTemp;
  uint16_t humidity;
  uint16_t pressure;
  uint16_t conductivity;
  uint16_t battery;

  uint32_t time;
  uint32_t crc;
};

// -------------------- CRC32 -------------------
uint32_t crc32_update(uint32_t crc, uint8_t data) {
  crc ^= data;
  for (uint8_t i = 0; i < 8; i++) {
    if (crc & 1) crc = (crc >> 1) ^ 0xEDB88320UL;
    else         crc >>= 1;
  }
  return crc;
}

template<typename T>
uint32_t crc32_calc(const T& obj, size_t lenWithoutCRC) {
  const uint8_t* p = (const uint8_t*)&obj;
  uint32_t crc = 0xFFFFFFFFUL;
  for (size_t i = 0; i < lenWithoutCRC; i++) {
    crc = crc32_update(crc, p[i]);
  }
  return ~crc;
}

// -------------------- STATE -------------------
uint32_t lastCounter[7] = {0};
bool     hasLast[7]     = {false};

// -------------------- HELPERS -----------------
void handlePacket(const DataPacket& p, uint8_t pipeNum) {
  uint8_t id = p.nodeId;

  float rtdT  = p.rtdTemp / 100.0f;
  float bmeT  = p.bmeTemp / 100.0f;
  float hum   = p.humidity / 100.0f;
  float pres  = p.pressure;
  float cond  = p.conductivity / 100.0f;
  float batt  = p.battery / 1000.0f;

  Serial.print("Node ");
  Serial.print(int(id));
  Serial.print("  cnt=");
  Serial.print(p.counter);
  Serial.print("  t(ms)=");
  Serial.print(p.time);
  Serial.print("  RTD=");
  Serial.print(rtdT, 4);
  Serial.print("  T=");
  Serial.print(bmeT, 4);
  Serial.print("  RH=");
  Serial.print(hum, 4);
  Serial.print("  P=");
  Serial.print(pres, 4);
  Serial.print("  C=");
  Serial.print(cond, 4);
  Serial.print("  Vbat=");
  Serial.println(batt, 4);

  char fname[16];
  sprintf(fname, "node%d.txt", int(id));
  File f = SD.open(fname, FILE_WRITE);
  if (f) {
    f.print(id); f.print(" ");
    f.print(p.counter); f.print(" ");
    f.print(p.time); f.print(" ");
    f.print(rtdT, 4); f.print(" ");
    f.print(bmeT, 4); f.print(" ");
    f.print(hum, 4); f.print(" ");
    f.print(pres, 4); f.print(" ");
    f.print(cond, 4); f.print(" ");
    f.println(batt, 4);
    f.close();
  }
}

// -------------------- SETUP / LOOP -----------
void setup() {
  Serial.begin(115200);
  // Serial.print("RX DataPacket size = ");
  // Serial.println(sizeof(DataPacket));

  SD.begin(10);

  radio.begin();
  radio.setDataRate(RF24_250KBPS);
  radio.setPALevel(RF24_PA_LOW);
  radio.setChannel(108);
  radio.setAutoAck(true);
  radio.enableDynamicPayloads();
  radio.enableAckPayload();  
  radio.setPayloadSize(32);
  radio.setCRCLength(RF24_CRC_16);
  radio.setRetries(5, 15);
  for (int i = 0; i < 6; i++) {
    radio.openReadingPipe(i + 1, pipes[i]); // pipes 1..6
  }

  radio.startListening();

  Serial.println("Receiver ready.");
}

void loop() {
  if (radio.available()) {
    uint8_t pipeNum;
    radio.available(&pipeNum);

    DataPacket pkt;
    radio.read(&pkt, sizeof(pkt));

    uint32_t c = crc32_calc(pkt, sizeof(DataPacket) - sizeof(uint32_t));
    if (c != pkt.crc || pkt.type != 0x01) {
      Serial.println("Bad CRC or type");
      return;
    }

    uint8_t id = pkt.nodeId;
    if (id >= 1 && id <= 6) {
      if (hasLast[id]) {
        if (pkt.counter > lastCounter[id] + 1) {
          Serial.print("Node ");
          Serial.print(id);
          Serial.print(" missed ");
          Serial.print(pkt.counter - lastCounter[id] - 1);
          Serial.println(" packets");
        }
      }
      hasLast[id] = true;
      lastCounter[id] = pkt.counter;

      handlePacket(pkt, pipeNum);
    }
  }
}

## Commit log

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2021-10-19 austin's updates
    [geophonetdsconductschem.kicad_pcb, geophonetdsconductschem.sch]
2021-10-19 Malichi's update
    [TDS_stake_pipe_connector v1.f3d, modified solar panel housing v1.f3d, sensor_cap v1.f3z]
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2022-01-05 malichi update
    [spike_v3 v1.f3d, spike_v3 v1.ipt]
2022-02-05 malichi updtae
    [smart penetrometer.sch]
2022-03-19 moved folders around
    [Housing v3 .f3d, Housing v3 .stl, Housing v3 part 2 .f3d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]
2022-03-19 created v0.4
    [Housing v3 .f3d, Housing v3 .stl, Housing v3 part 2 .f3d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]
2022-03-19 malichi updates
    [sensor_cap_v3 v1.f3z, sensor_cap_v3 v1.stl, sensor_cap_v4.f3z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]
2022-04-23 updates with gerb files.
    [smart penetrometer-B_Cu.gbr, smart penetrometer-B_Mask.gbr, smart penetrometer-B_Paste.gbr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]
2022-05-05 Create norona_evolution_1 v3.f3d
    [norona_evolution_1 v3.f3d]
2022-07-01 repository reorganization
    [Housing v3 .f3d, Housing v3 .stl, Housing v3 part 2 .f3d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]
2022-07-12 code update
    [smart penetrometer update.sch]
2022-07-26 schematic update
    [smart penetrometer update.sch]
2022-07-28 SCHEMATIC UPDAYE
    [smart penetrometer update.sch]
2022-11-12 no change
    [smart penetrometer update.kicad_pcb, smart penetrometer update.sch]
2023-04-07 Fix PCB Design
    Several traces missing in PCB Design.
    [smart penetrometer update-B_Cu.gbr, smart penetrometer update-B_Mask.gbr, smart penetrometer update-B_Paste.gbr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]
2023-04-07 moved v1 to v0.4.0
    [smart penetrometer update-B_Cu.gbr, smart penetrometer update-B_Mask.gbr, smart penetrometer update-B_Paste.gbr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]
2023-04-10 Edited V0.4.0 to add CAD and Code folders and files
    Added CAD and code folders with files for editing in V0.4.0, and deleted unnecessary files in the PCB folder
    [Housing v4 .f3d, Housing v4 .stl, Housing v4 part 2 .f3d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]
2023-05-19 modified the CAD model for the geophone
    [Housing v4 .f3d, Housing v4 .stl, Housing v4 part 2 .f3d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]
2023-05-19 cleaned up v0.4.0 and added some tasks
    [smart_penetrometer_v0.4.0.csv, smart_penetrometer_v0.4.0.kicad_pcb, smart_penetrometer_v0.4.0.kicad_sch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]
2023-05-19 added 0.4.1
    [Housing v4 part 2.f3d, Housing v4 part 2.stl, Housing v4.f3d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]
2023-05-19 pcb update
    [smart penetrometer.kicad_pcb, smart penetrometer.kicad_sch]
2023-05-19 PCB V0.4.1 UPDATE
    [smart penetrometer.kicad_pcb, smart penetrometer.kicad_sch]
2023-07-14 reorganized structure
    [Housing v3 .f3d, Housing v3 .stl, Housing v3 part 2 .f3d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]
2023-07-14 CAD update
    [Housing v4.1 part 1.stl, Housing v4.1 part 2.f3d, Housing v4.1 part 2.stl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]
2023-07-17 pcb and cad update
    [Housing v5.0 part 1 v6.stl, Housing v5.0 part 2.step, Housing v5.0 part 2.stl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]
2023-07-28 v5 update
    [Housing v4.1 part 2.f3d, Housing v4.1 part 2_.stl, Housing v4.1.stl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]
2023-10-13 added conductivity penetrometer version
    [Housing v5.0b.stl, Solar Cell Attachment v5.0.f3d, Solar Cell Attachment v5.0.stl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]
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2023-11-27 reorganized folders
    [Housing1 V0.5.0.f3d, Housing1 V0.5.0.stl, Housing1 V0.5.0b.stl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]
2023-11-27 rename files
    [Housing1.f3d, Housing1.stl, Housing2.f3d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]
2023-11-28 added BOM
    [BOM.xlsx]
2024-01-29 version 5.2 upload
    [BOM.xlsx, Housing1.f3d, Housing1.stl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]
2024-02-24 wireless communication update
    [smart penetrometer.kicad_sch]
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2024-04-02 V0.6.0 release
    [smart penetrometer.csv, smart penetrometer.kicad_pcb, smart penetrometer.kicad_sch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]
2024-04-03 V0.6.0 CAD upload
    [Housing1.f3d, Housing1.step, Housing1.stl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]
2024-04-06 Update smart penetrometer.kicad_pcb
    [smart penetrometer.kicad_pcb]
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2024-04-08 created the Columbia folder
    [BOM.xlsx, Housing v3 .f3d, Housing v3 .stl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]
2024-04-08 spike-only code
    [spike_PCB-B_Cu.gbr, spike_PCB-B_Mask.gbr, spike_PCB-B_Paste.gbr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]
2024-04-15 Mississippi v0.1
    [spike_PCB-B_Cu.gbr, spike_PCB-B_Mask.gbr, spike_PCB-B_Paste.gbr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]
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2024-09-14 Created spot for base station files
    Kicad for receiver PCB in base station
    [SPECIES_receiver.kicad_pcb, SPECIES_receiver.kicad_sch]
2025-01-03 updated base station receiver pcb
    decreased board size, flipped nRF pinout, and added clearer silkscreen labels
    [SPECIES_receiver.kicad_pcb, SPECIES_receiver.kicad_sch]
2025-01-03 grounded mounting holes
    [SPECIES_receiver.kicad_pcb]
2025-01-03 update readme
    describe base station folder as well as clarify apparent "loose connections" on the pcb file
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2025-07-14 updated two errors on PCB
    [spike_PCB-B_Cu.gbr, spike_PCB-B_Mask.gbr, spike_PCB-B_Paste.gbr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]
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2025-11-05 Create BOM-SPECIES-Columbia-v0.6.2.xlsx
    uploaded base station components
    [BOM-SPECIES-Columbia-v0.6.2.xlsx]
2026-01-06 added cap cad file
    [cap_v0.7.0.0001.ipt, cap_v0.7.0.ipt]
2026-01-06 added screw holes to cap cad
    [cap_v0.7.0.0001.ipt, cap_v0.7.0.0003.ipt, cap_v0.7.0.ipt]
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2026-01-07 v2 of cap 0.7.0 added
    [cap2_v0.7.0.0002.ipt, cap2_v0.7.0.ipt, cap2_v0.7.0.stl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]
2026-01-08 revised sizing errors in cap2
    [cap2_v0.7.0.0002.ipt, cap2_v0.7.0.0004.ipt, cap2_v0.7.0.ipt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]
2026-01-13 uploaded new cap design (3)
    [cap2_v0.7.0.ipt, cap2_v0.7.0.stl, cap3_v0.7.0.0002.ipt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]
2026-01-23 0.7.0 updated body and base
    [Housing1.ipt, cap3_v0.7.0.0002.ipt, cap3_v0.7.0.0003.ipt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]
2026-01-23 stls and changed names
    [Housing1_v0.7.0.ipt, Housing1_v0.7.0.stl, base_v0.7.0.ipt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]
2026-01-26 minor updates to base
    [base_v0.7.0.0001.ipt, base_v0.7.0.ipt, base_v0.7.0.stl]
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2026-01-27 wrong again so minor sizing update
    [base_v0.7.0.0003.ipt, base_v0.7.0.0004.ipt, base_v0.7.0.ipt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]
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2026-02-04 uploaded most recent cap
    [solar cap 2_.ipt, solar cap 2_.stl, solar cap 2_.stp]
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2026-05-29 reduced rod to 36 in for free shipping
    [BOM-SPECIES-Columbia-v0.7.0.xlsx]
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2026-07-27 moved bom to better place
    [BOM-SPECIES-Columbia-v0.7.0.xlsx]
2026-07-27 converted BOM to excel file
    [smart penetrometer.kicad_pro.xlsx]

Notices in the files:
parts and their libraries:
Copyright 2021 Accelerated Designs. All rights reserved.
